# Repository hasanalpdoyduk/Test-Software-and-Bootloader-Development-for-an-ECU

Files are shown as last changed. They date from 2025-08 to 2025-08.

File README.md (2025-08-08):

# Test Software and Bootloader Development for an ECU

A bootloader has been developed that enables firmware updates without external programmers. The system runs on a 16-bit dsPIC33 microcontroller and supports CAN and UART interfaces.

Software is securely transferred via one of these interfaces and written to the microcontroller's memory using a block-based architecture that ensures data integrity during interrupts. To streamline the update process, a Python-based graphical user interface (GUI) was created for real-time control and monitoring.

Furthermore, a custom board containing the dsPIC33 MCU was designed and manufactured, successfully testing the bootloader and a PWM control implementation.
## Hardware Components

To initially load the bootloader onto the microcontroller or test the PWM control code, an external debugger is required. In this project, Microchip’s **PICkit 5** is used to program the dsPIC33 device.

| Type | Component |
| --- | --- |
| Microcontroller | [dsPIC33](https://ww1.microchip.com/downloads/aemDocuments/documents/OTH/ProductDocuments/DataSheets/dsPIC33EVXXXGM00X-10X-Family-Data-Sheet-DS70005144H.pdf) |
| CAN Transceiver | [MCP2561](https://ww1.microchip.com/downloads/en/DeviceDoc/20005167C.pdf) |
| LDO | [LF50](https://www.st.com/resource/en/datasheet/lfxx.pdf) |
| TVS Diode| [SMAJ36CA](https://www.vishay.com/docs/88390/smaj50a.pdf) |
| Schottky Diode| [SS8PH10HM3](https://www.vishay.com/docs/88989/ss8ph10.pdf) |

In addition to main components, other hardware parts such as resistors, capacitors, connectors, and oscillators are listed in the [Bill of Materials (BOM)](https://github.com/hasanalpdoyduk/Test-Software-and-Bootloader-Development-for-an-ECU/blob/main/KiCAD/ECU_SW_Control/Production_Files/BOM/ECU_SW_Control.csv).

## Block Diagram

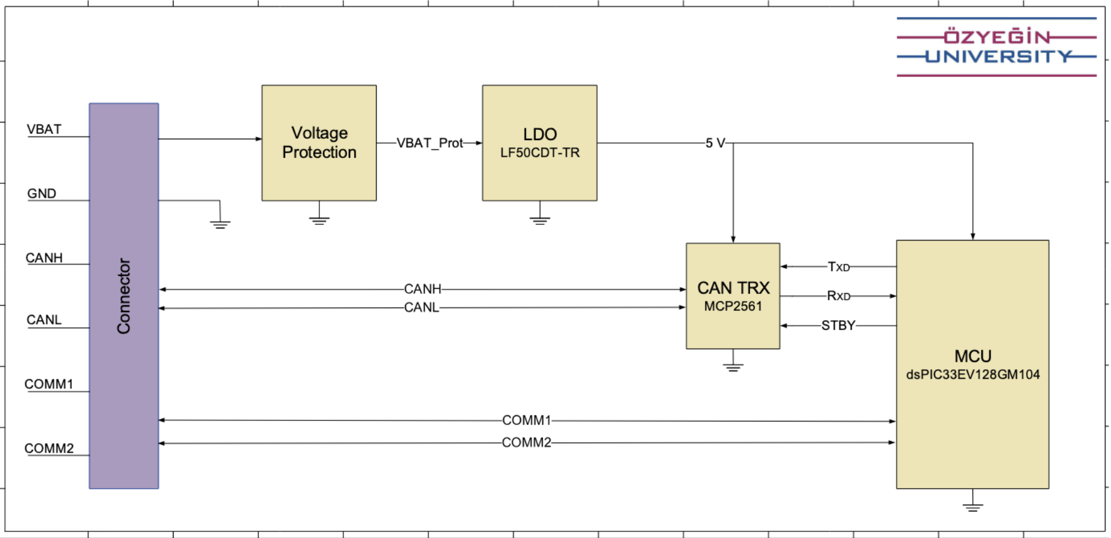
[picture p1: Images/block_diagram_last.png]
Block Diagram


The fully assembled PCB is shown here: [3D View of PCB](https://github.com/hasanalpdoyduk/Test-Software-and-Bootloader-Development-for-an-ECU/blob/main/Images/3D_view.pdf)

## Tools & Libraries

- KiCad: Used for schematic and PCB design.

- MATLAB Simulink Device Blocks for Microchip: Used to model and generate initial versions of embedded code.

- MPLAB X IDE: Used to compile and flash generated C code to the dsPIC33 MCU.

- Python (PyQt): Used for GUI development to support user interaction and test control.

## Supporting Sources

All technical details and explanations related to the project are available in the [project report](https://github.com/hasanalpdoyduk/Test-Software-and-Bootloader-Development-for-an-ECU/blob/main/Report_Presentation/EE402_Final_Report_AlpDoyduk_S025015_I%CC%87smail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). For more in-depth insights or specific inquiries, feel free to reach out via GitHub or refer to the resources listed below.

- [MCC dsPIC33 Bootlader - Video Guide](https://www.youtube.com/watch?v=2LhW11LbNhY): A step-by-step YouTube tutorial demonstrating how to implement a bootloader for dsPIC33 using Microchip Code Configurator (MCC).

- [Microchip Bootloader Library for 16-bit Devices](https://www.microchip.com/en-us/software-library/dspic33-pic24-bootloader): Official documentation and downloadable libraries for implementing bootloaders on 16-bit dsPIC33/PIC24 microcontrollers.

- [16-bit Bootloader Using MCC - Online Course](https://mu.microchip.com/16-bit-bootloaders-using-mcc-device-side): A Microchip University course explaining how to develop a bootloader for dsPIC33 using MCC, covering both theory and practice.
## Authors

- [Hasan Alp Doyduk](https://www.github.com/hasanalpdoyduk)
- [Ismail Akbaş](https://www.github.com/ismailakbas)

Supervised by: Asst. Prof. Umut Başaran

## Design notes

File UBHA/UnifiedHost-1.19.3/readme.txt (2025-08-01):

# README	General information
* Unified Bootloader Host Application 
- Used with the MCC Bootloader Generated Software Library for 8-bit or 16-bit MCU devices, or the 32-bit AN1388 bootloader.
- The graphical front-end of the 8-bit, 16-bit and 32-bit Bootloader project.

# Support
Email: MCC_Support@microchip.com
This application requires the Java 1.8 runtime.
For the required Java FX support, and an alternative source to the legacy Java installer can be found here:
Azul Zulu Community OpenJDK with OpenJFX is recommended; OpenJFX is required for use with UBHA.
https://www.azul.com/downloads/zulu-community/?&version=java-8-lts&package=jdk-fx 

Ensure to select the appropriate operating system, and architecture (32/64 bit).
Additional info: https://www.azul.com/products/zulu-enterprise/jdk-comparison-matrix/

Users of Microchip products can receive assistance through several channels:

 - Distributor or Representative
 - Local Sales Office
 - Field Application Engineer (FAE)
 - Technical Support

Customers should contact their distributor, representative or Field Application Engineer (FAE) for support.
Local sales offices are also available to help customers.
A listing of sales offices and locations may be found on the [Microchip web site][3].

Technical support is available through the [Microchip web site][4].

# CHANGELOG	A detailed changelog, intended for programmers
v 0.1.9:	Added readme, added logger, added checksum support to PIC32; added handling for record type 0x05 (currently ignored)
v 0.1.10:	Internal release
v 0.1.11:	Internal release
v 0.1.14:	Added PIC32 CRC bytes used at end of packets. Added Erase feature to USB PIC32 command chain. Extended Timeouts added support for 24-bit packet length.
v 0.1.15:	Fixed bug in PIC16 erase being half expected length during command chain. Added support for larger PIC18 device checksum commands, appending over previous Access Key bytes.
v 1.0.0:	Release version to support PIC24 family of devices. Added beta support for AVR devices.
v 1.15.0:   Release version to support dsPIC33 family of devices. Release support for AVR devices.
v 1.15.1:   Fixed bugs to support PIC-IOT WG Development Board, phantom byte for degenerate blocks and restrict data packet size to MAX_PACKET_SIZE - HEADER_SIZE.
v 1.16.0:   AVR code protocol modified to handle large future devices.
v 1.16.1:   Updated HID4JAVA library used for USB communication. Updates to AVR support to support MCC generated code. Extended PIC32 timeout(s) to 20s (from 8) UDP, USB
v 1.16.2:   32-bit devices no longer wait for responds from Reset Command. Bug fixes for 16-bit support: 1) Self Verify issue with larger parts with 2) no report, 3) End Address corruption on read properties, 4) Exception thrown on UART disconnect.
v 1.16.3:   Corrects an issue with 16-bit devices where flash data was unable to be written if located at the end of the last flash page.
v 1.17.0:   Add CAN and CAN-FD support for PIC24/dsPIC devices.  Expand console logging capability for PIC24/dsPIC devices.
v 1.17.1:   Improved console logging messages. Added provision to package the dependencies as a hotfix.
v 1.18.0:   Add I2C support for PIC24/dsPIC devices. Added support for select PIC18F Q device families (Q40, Q41, Q43, Q83, Q84).
v 1.19.0:   Add LIN support for PIC24/dsPIC devices. Fix issue causing readback errors when only a partial instruction worth of data is specified in the .hex file.
v 1.19.1:   Fix CAN DLL issue with latest USB drivers
v 1.19.2:   Fix MCP2221 DLL issue with latest drivers
v 1.19.3:   Robustness improvements to 16-bit UI implementation when UART driver loading fails.
            Fix issue of CAN BRS setting option being ignored.

# NEWS	A basic changelog, intended for users
-Incremented version information; see Changelog
-Added readme file on release of version: 0.1.14
-Added Checksum support for PIC32
-Bug fixes, Added Release Notes v 0.1.15 along with readme file. Added support for up to 32-bit checksum value calculation.
-Added Synch Byte expectation to AVR packet support.
-Fixed Typo in Help-->About text which indicated incorrect Utility version
-Added logger support requires launching from command prompt with below text:
* -Djava.util.logging.config.file="C:\<DirectoryLocation>"
- Bugfix for 16-bit flash write.

# Known Issues
- When using a version of java greater than v1.8.0_251, selecting a UART COM port and selecting "Apply" causes the Unified Bootloader Host Application to crash. In order to avoid this please ensure to use
a version of java at or below version 1.8.0_251. 
- The warning 'Application Offset exist between ROWS/PAGE boundaries' might be shown incorrectly, even though the application offset is at the start of a page. Please make sure that the application start adress is at the beginning of a page by referring to the device datasheet.

# Debug Log
The UBHA supports the ability to view Debug Logger message through use of the packaged logging.properties file.
i.e.: To Launch from Command Prompt
>java -Djava.util.logging.config.file="<Drive: e.g. C>:\<MyDirectory>\<UnifiedHost-version>\logging.properties" -jar UnifiedHost-<version>.jar

# INSTALL	Installation instructions
Installation of Java JRE

# COPYING / LICENSE	Copyright and licensing information
See LICENSE.txt for licensing information.

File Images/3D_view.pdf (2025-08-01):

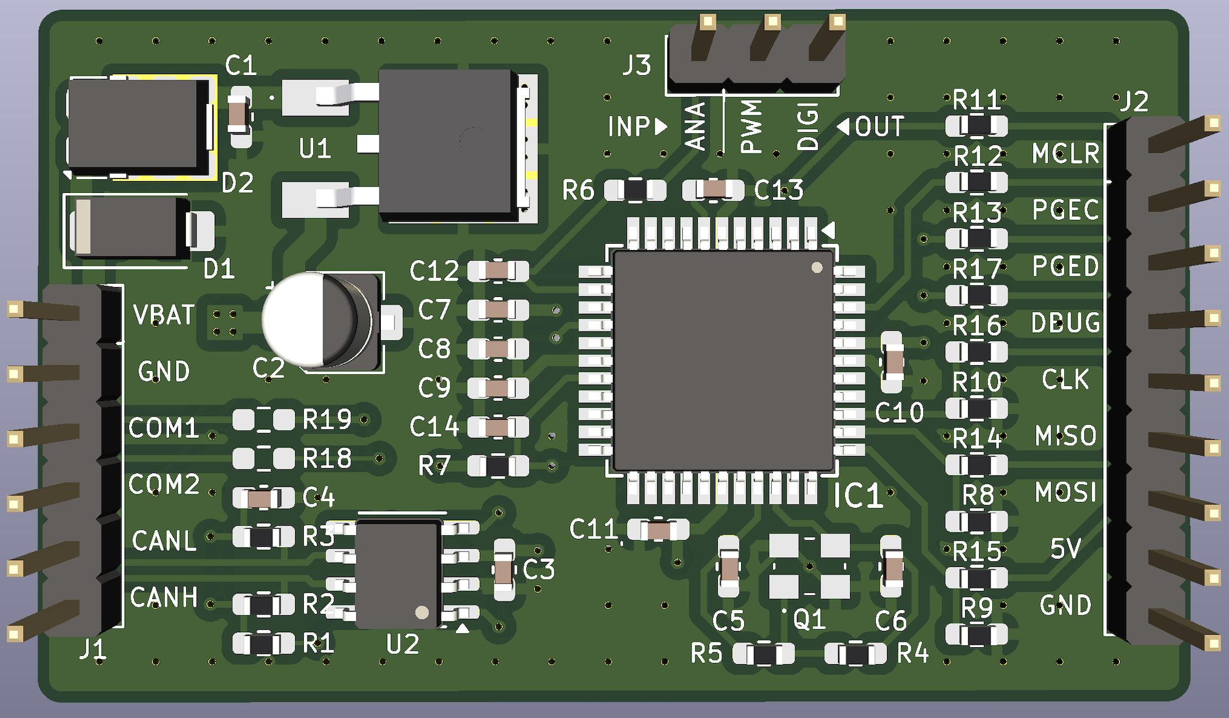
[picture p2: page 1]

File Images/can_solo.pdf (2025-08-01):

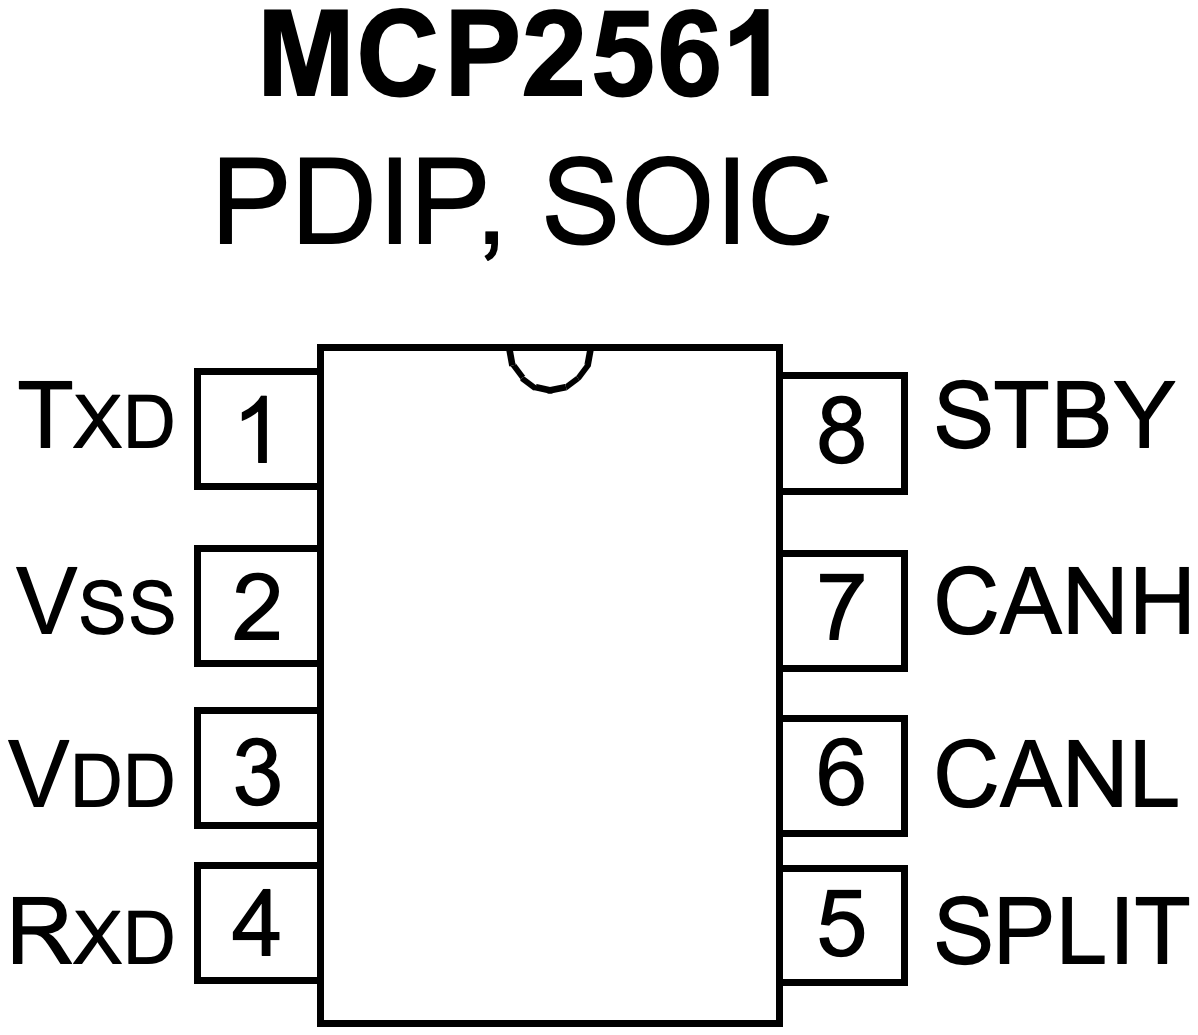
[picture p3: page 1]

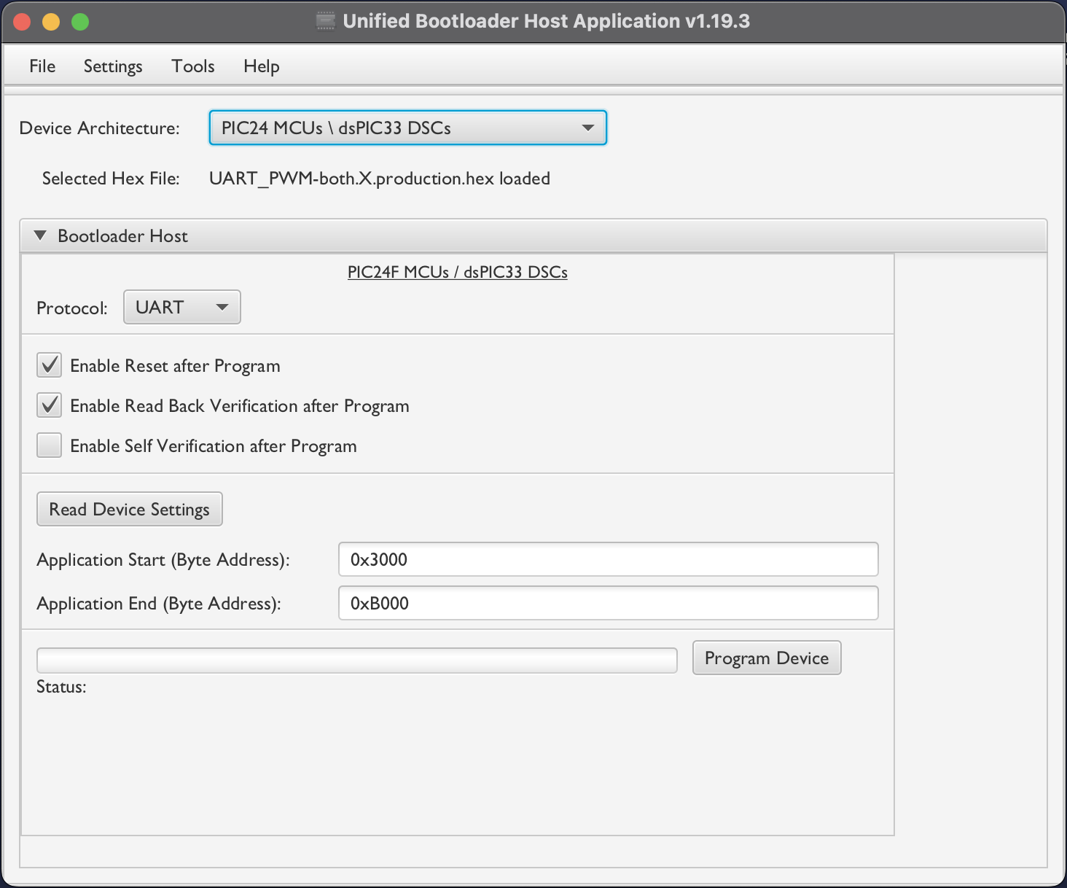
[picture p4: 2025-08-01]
Images/UBHA_select_HEX.png

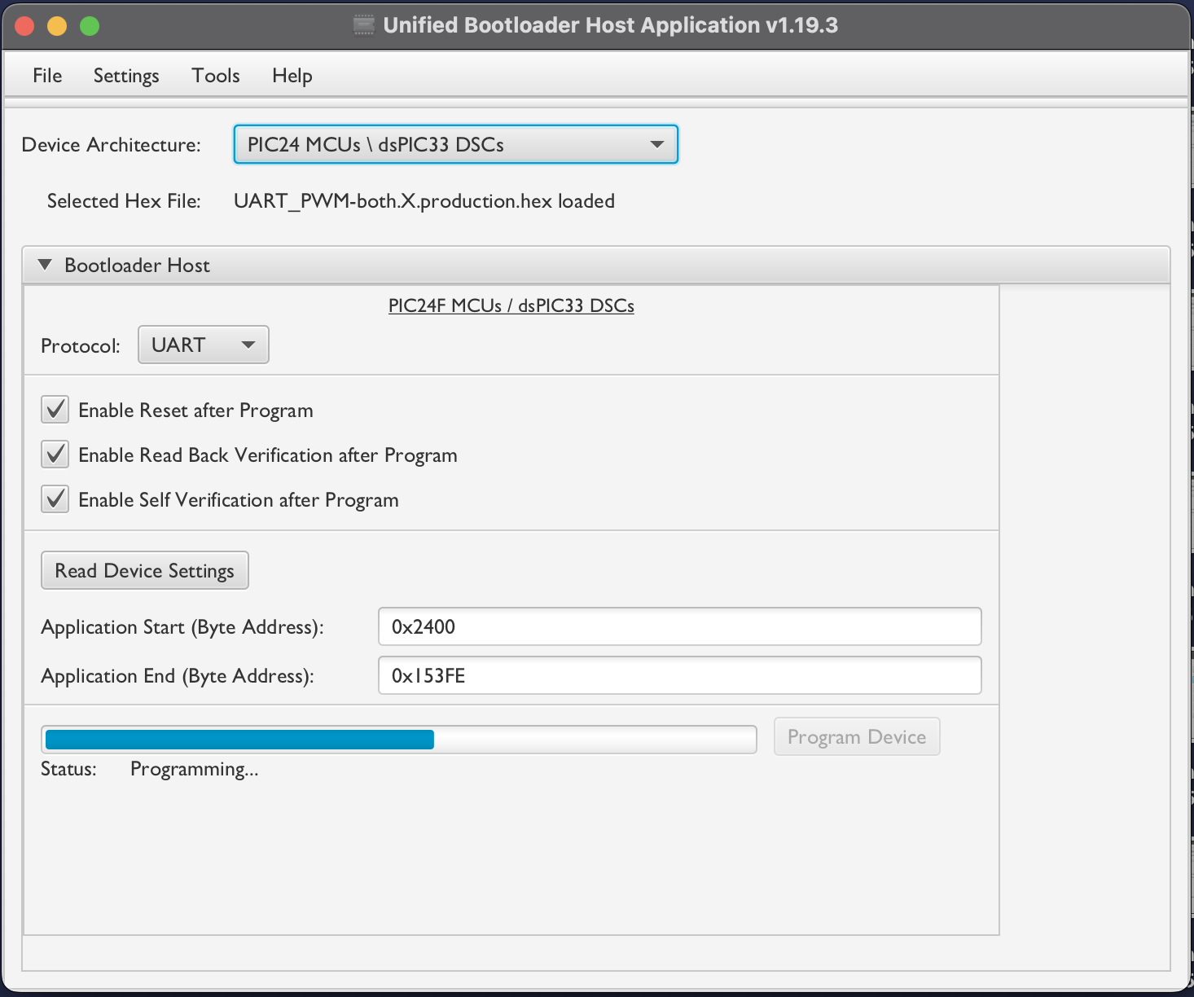
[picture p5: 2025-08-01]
Images/UBHA_programming.png

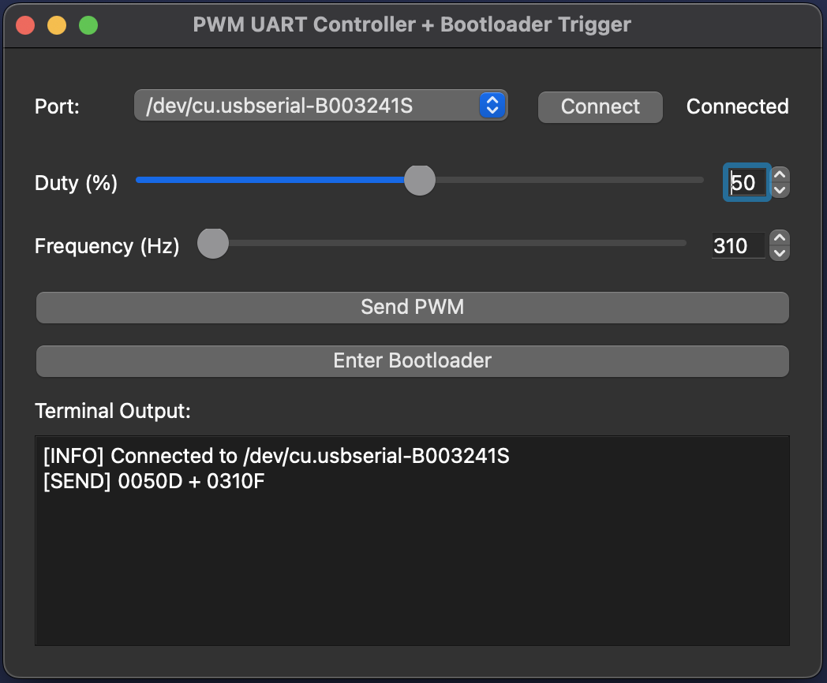
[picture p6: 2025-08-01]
Images/UART_GUI1.png

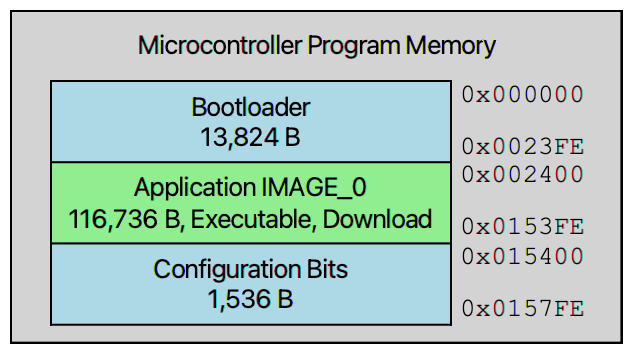
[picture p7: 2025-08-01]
Images/bootloader_register_map.png

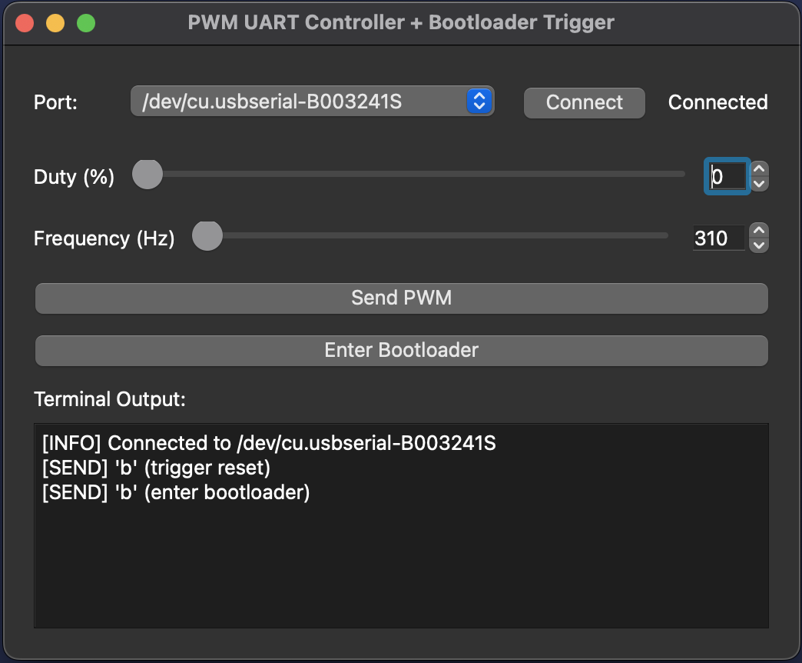
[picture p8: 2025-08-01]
Images/Boot_GUI_enter_b.png

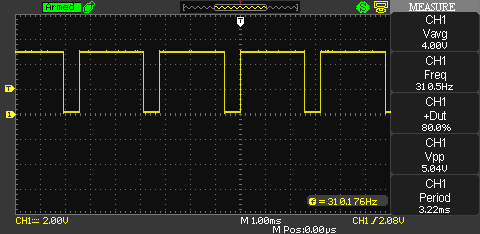
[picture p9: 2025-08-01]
Images/OscillatorSs/ADS00002.BMP

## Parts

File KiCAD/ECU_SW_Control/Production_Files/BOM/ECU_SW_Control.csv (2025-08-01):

Reference | Value | Footprint | Qty | DNP | Ordering_Code | Ordering_Link
C1,C3 | 0.1uF/50V | Capacitor_SMD:C_0603_1608Metric_Pad1.08x0.95mm_HandSolder | 2 |  | CGA3E2X7R1H104K080AA | -- mixed values --
C2 | 2.2uF/50V | Capacitor_SMD:CP_Elec_4x5.3 | 1 |  | SC1H225M04005VR | https://ozdisan.com/pasif-komponentler/kapasitorler/aluminyum-kapasitorler/SC1H225M04005VR/27464
C4 | 4700pF/50V | Capacitor_SMD:C_0603_1608Metric_Pad1.08x0.95mm_HandSolder | 1 |  | CL10B472KB8WPNC | https://www.digikey.com/en/products/detail/samsung-electro-mechanics/CL10B472KB8WPNC/5961016
C5,C6 | 8.2pF/50V | Capacitor_SMD:C_0603_1608Metric_Pad1.08x0.95mm_HandSolder | 2 |  | CL10C8R2CB81PNC | https://www.digikey.com/en/products/detail/samsung-electro-mechanics/CL10C8R2CB81PNC/5961050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
C7 | 2.2uF/25V | Capacitor_SMD:C_0603_1608Metric_Pad1.08x0.95mm_HandSolder | 1 |  | GRT188C71E225KE13D | https://www.digikey.com/en/products/detail/murata-electronics/GRT188C71E225KE13D/16033473
C8,C9,C11 | 100nF/50V | Capacitor_SMD:C_0603_1608Metric_Pad1.08x0.95mm_HandSolder | 3 |  | CL10B104KB8WPNC | https://www.digikey.com/en/products/detail/samsung-electro-mechanics/CL10B104KB8WPNC/5961338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
C10 | 100nF/25V | Capacitor_SMD:C_0603_1608Metric_Pad1.08x0.95mm_HandSolder | 1 |  | CGA3E2X7R1E104K080AA | https://www.digikey.com/en/products/detail/tdk-corporation/CGA3E2X7R1E104K080AA/2443145
C12,C14 | 10nF/50V | Capacitor_SMD:C_0603_1608Metric_Pad1.08x0.95mm_HandSolder | 2 |  | GCM188R71H103KA37D | https://www.digikey.com/en/products/detail/murata-electronics/GCM188R71H103KA37D/1641652
C13 | 10uF/16V | Capacitor_SMD:C_0603_1608Metric_Pad1.08x0.95mm_HandSolder | 1 |  | GRT188R61C106ME13D | https://www.digikey.com/en/products/detail/murata-electronics/GRT188R61C106ME13D/5416740
D1 | SMAJ36CA | Diode_SMD:D_SMA | 1 |  | SMAJ36CA-AT/TR7 | https://ozdisan.com/guc-yari-iletkenleri/diyotlar-modul-diyotlar-ve-dogrultucular/tvs-diyotlar/SMAJ36CA-ATTR7/973895
D2 | V10P10HM3_A_H | Package_TO_SOT_SMD:TO-277A | 1 |  | V10P10HM3_A/H | https://www.digikey.com/en/products/detail/vishay-general-semiconductor-diodes-division/V10P10HM3-A-H/5427050
IC1 | dsPIC33EV128GM104 | Package_QFP:TQFP-44_10x10mm_P0.8mm | 1 |  | dsPIC33EV128GM104 | https://www.microchip.com/en-us/product/dspic33ev128gm104
J1 | Conn_01x06 | Connector_PinHeader_2.54mm:PinHeader_1x06_P2.54mm_Vertical | 1 |  | 5PS1SDA85-106G0NNNAL-00 | https://ozdisan.com/Product/Detail/354014/5PS1SDA85-106G0NNNAL-00
J2 | Conn_01x09 | Connector_PinHeader_2.54mm:PinHeader_1x09_P2.54mm_Vertical | 1 |  | DS1023-1X9S21 | https://ozdisan.com/Product/Detail/421997/DS1023-1X9S21
J3 | Conn_01x03 | Connector_PinHeader_2.54mm:PinHeader_1x03_P2.54mm_Vertical | 1 |  | DS1023-1X3SF11 | https://ozdisan.com/Product/Detail/454405/DS1023-1X3SF11
Q1 | CX3225CA-12MHz | ECU_SW_Control_lib:CX3225SB40000D0FLJCC | 1 |  | CX3225CA12000D0HSSCC | https://www.digikey.com/en/products/detail/kyocera-avx/CX3225CA12000D0HSSCC/4453836
R1 | 300R/1% | Resistor_SMD:R_0603_1608Metric_Pad0.98x0.95mm_HandSolder | 1 |  | ERJ-3EKF3000V | https://ozdisan.com/passive-components/resistors/smt-smd-and-chip-resistors/ERJ-3EKF3000V/614721
R2,R3 | 60.4R/1% | Resistor_SMD:R_0603_1608Metric_Pad0.98x0.95mm_HandSolder | 2 |  | ERJ-U03F60R4V | https://www.digikey.com/en/products/detail/panasonic-electronic-components/ERJ-U03F60R4V/11634997
R4 | 1M/1% | Resistor_SMD:R_0603_1608Metric_Pad0.98x0.95mm_HandSolder | 1 |  | ERJ-3EKF1004V | https://www.digikey.com/en/products/detail/panasonic-electronic-components/ERJ-3EKF1004V/196033
R5,R6,R11,R12,R13,R14,R15,R16,R17 | 100R/1% | Resistor_SMD:R_0603_1608Metric_Pad0.98x0.95mm_HandSolder | 9 |  | ERJ-3EKF1000V | https://www.digikey.com/en/products/detail/panasonic-electronic-components/ERJ-3EKF1000V/196074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
R7,R8,R9,R10 | 10k/1% | Resistor_SMD:R_0603_1608Metric_Pad0.98x0.95mm_HandSolder | 4 |  | ERJ-3EKF1002V | https://www.digikey.com/en/products/detail/panasonic-electronic-components/ERJ-3EKF1002V/196066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
R18,R19 | 0/5% | Resistor_SMD:R_0603_1608Metric_Pad0.98x0.95mm_HandSolder | 2 | DNP | 0603SAJ0000TDE | https://ozdisan.com/pasif-komponentler/direncler/smt-smd-ve-cip-direncler/0603SAJ0000TDE/602709
U1 | LF50_TO252 | ECU_SW_Control_lib:LF50CDTTRY | 1 |  | LF50CDT-TRY | https://www.digikey.com/en/products/detail/stmicroelectronics/LF50CDT-TRY/2193170
U2 | MCP2561-E-SN | Package_SO:SOIC-8_3.9x4.9mm_P1.27mm | 1 |  | MCP2561-E-SN | https://ozdisan.com/entegre-devreler-icler/interface-entegreleri/driver-receiver-ve-transceiver-entegreleri/MCP2561-ESN/457815

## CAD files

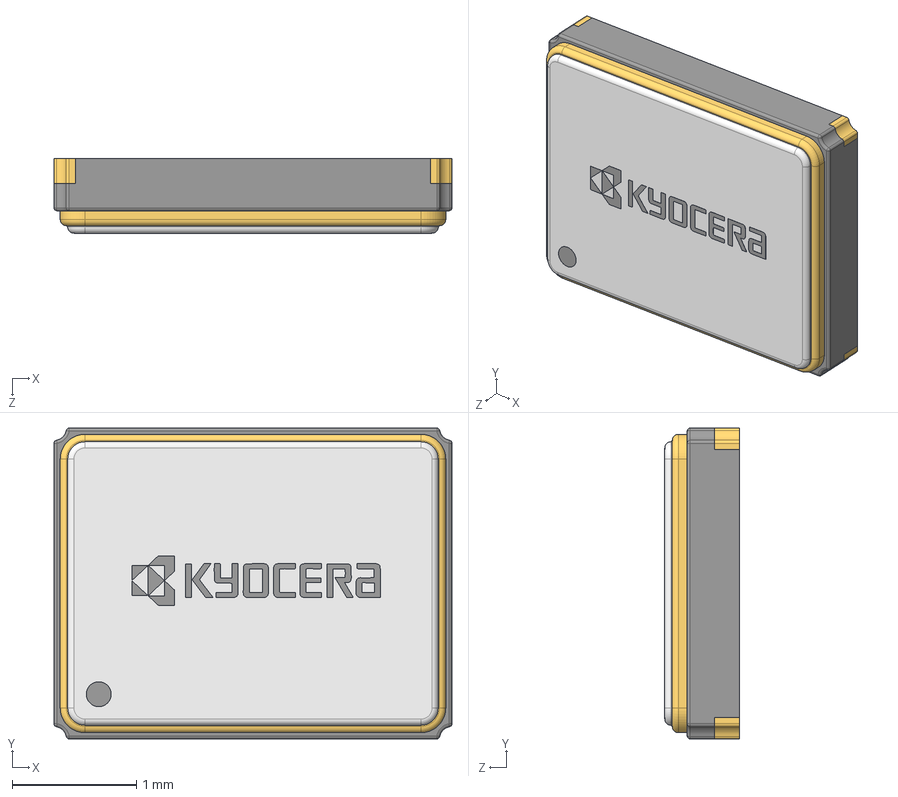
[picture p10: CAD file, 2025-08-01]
KiCAD/ECU_SW_Control/External_lib/LIB_CX3225CA12000D0KPSC1/CX3225CA12000D0KPSC1/3D/CX3225CA12000D0KPSC1.stp
3.20 x 2.50 x 0.601 mm
CX3225SB25000D0FFFCC_Pin 1 Chamfer
Kyocera Logo

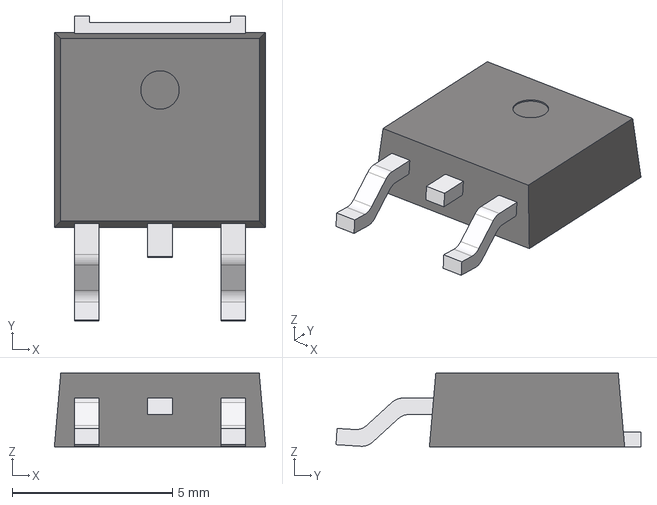
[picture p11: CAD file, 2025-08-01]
KiCAD/ECU_SW_Control/External_lib/LIB_LF50/3D/LF50CDT-TR.stp
6.60 x 9.53 x 2.30 mm

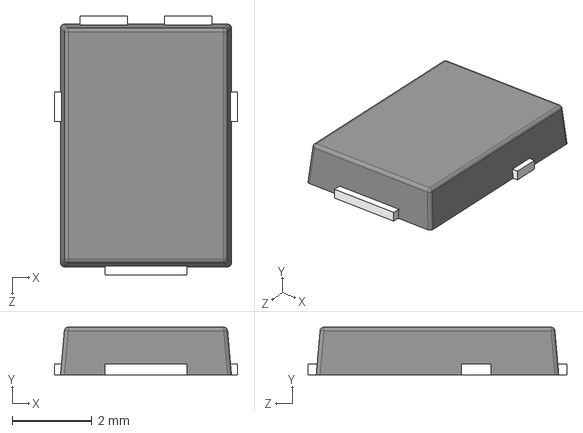
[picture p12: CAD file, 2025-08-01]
KiCAD/ECU_SW_Control/External_lib/LIB_V10P10HM3_A_H/V10P10HM3_A_H/3D/V10P10HM3_A_H.stp
4.60 x 1.20 x 6.50 mm

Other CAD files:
KiCAD/ECU_SW_Control/External_lib/LIB_CX3225CA12000D0KPSC1/CX3225CA12000D0KPSC1/Allegro/cx3225sb40000d0fljcc.psm
KiCAD/ECU_SW_Control/External_lib/LIB_CX3225CA12000D0KPSC1/CX3225CA12000D0KPSC1/DEHDL/cx3225ca12000d0kpsc1/chips/chips.prt
KiCAD/ECU_SW_Control/External_lib/LIB_V10P10HM3_A_H/V10P10HM3_A_H/Allegro/v10p10hm3_ah.psm
KiCAD/ECU_SW_Control/External_lib/LIB_V10P10HM3_A_H/V10P10HM3_A_H/DEHDL/v10p10hm3_a_h/chips/chips.prt

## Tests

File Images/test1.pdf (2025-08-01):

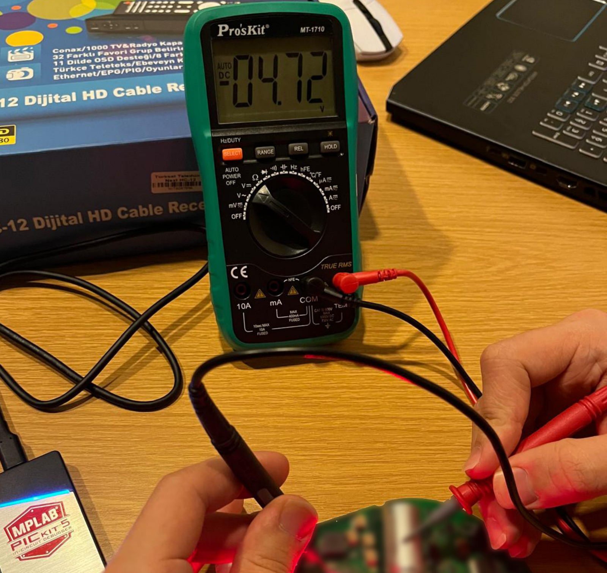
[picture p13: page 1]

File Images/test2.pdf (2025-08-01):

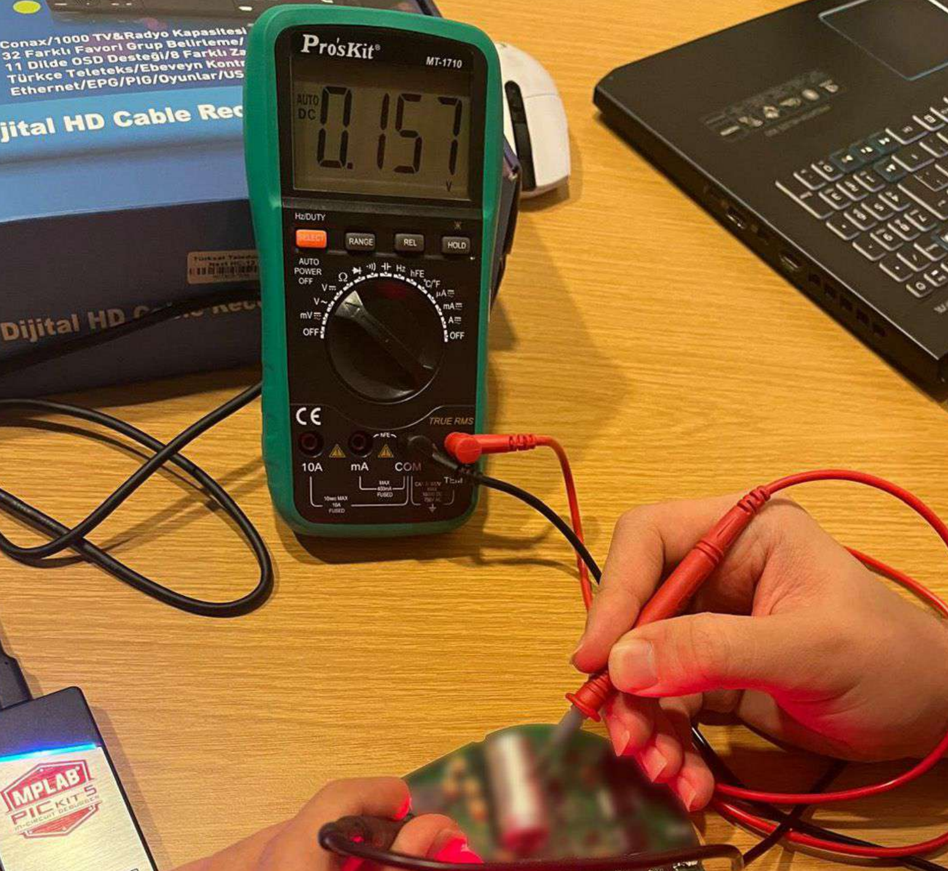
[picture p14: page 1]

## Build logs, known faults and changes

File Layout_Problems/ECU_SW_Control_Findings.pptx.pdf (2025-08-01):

# ECU SW CONTROL PROJECT DESIGN FINDINGS

# LF50CDT-TRY LDO

## - An LDO with 12V input voltage and 5V output voltage was used. Issues such as power dissipation and thermal analysis should be evaluated by considering parameters such

as ambient temperature and output current. I suggest you research this topic.

# Finding 1: Thermal Issue

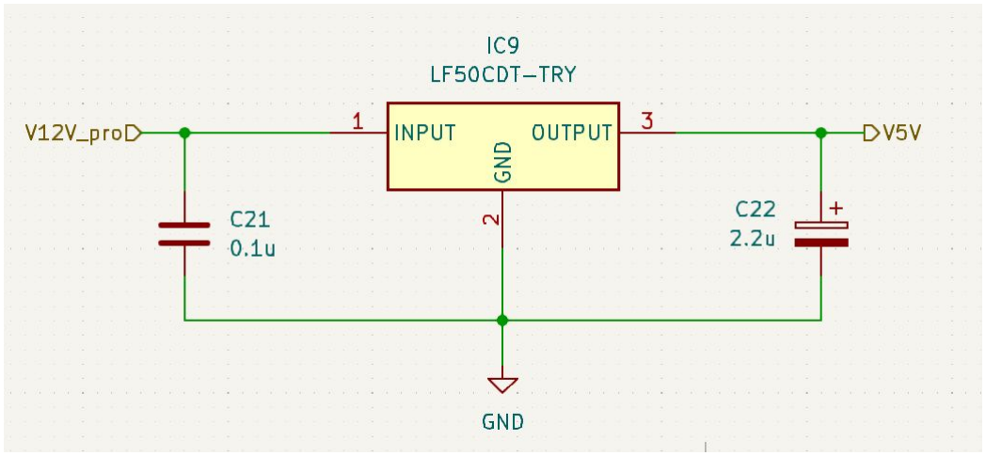
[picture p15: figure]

- Capacitors can be placed closer to the LDO input and output pins.

# Finding 2: Capacitor Placement

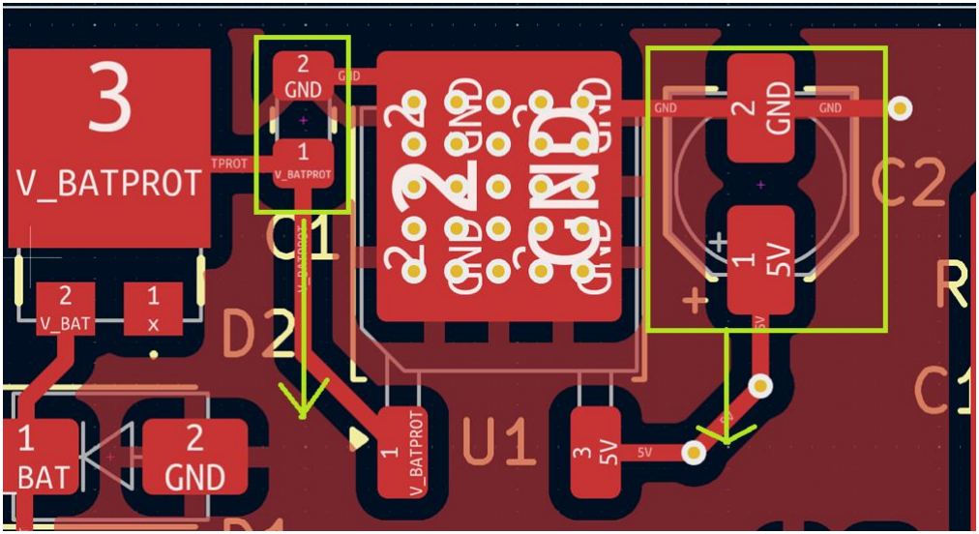
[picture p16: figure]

## - 5V can enter the Electrolytic capacitor after the LDO output pin and then be

distributed to the board from the 3rd layer with vias.
Via numbers are related to current capability. I suggest you to investigate.

# Finding 3: 5V Voltage

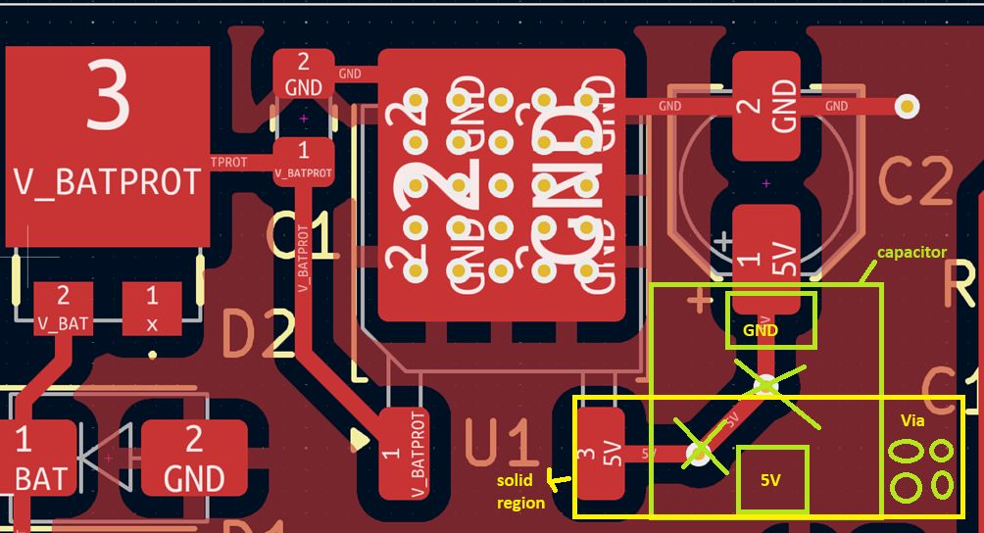
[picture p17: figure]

## - Battery voltage tracks can be thickened if necessary, according to the current

requirement of the system.
You can download and check the PCB Saturn Tool for current calculation.

# Finding 4: Current Capability

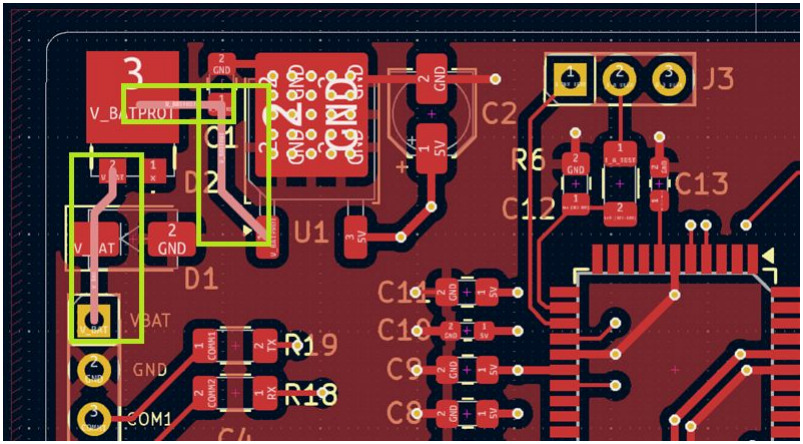
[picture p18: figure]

# CAN INTERFACE

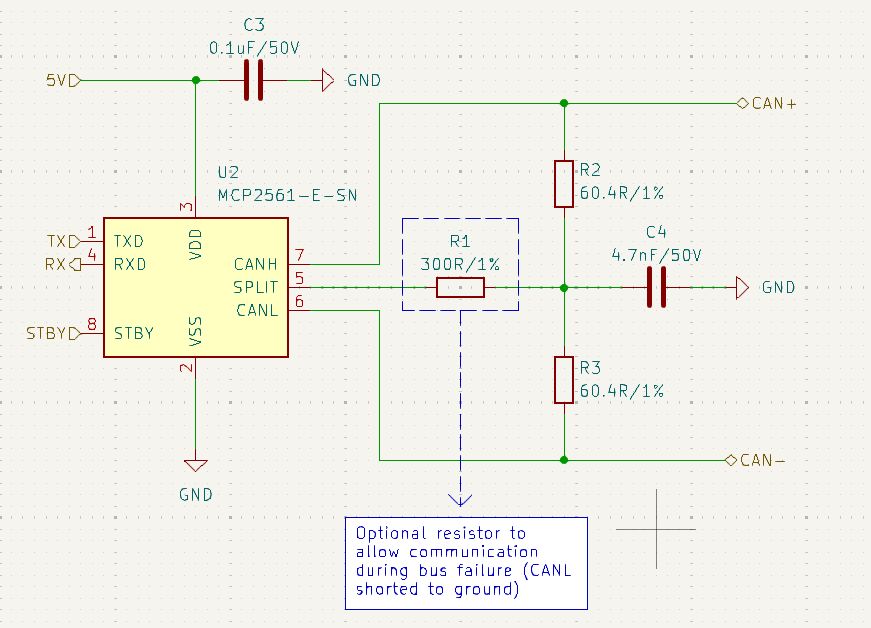
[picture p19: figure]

### https://www.onsemi.com/pub/Collater al/AND8169-D.PDF (https://www.onsemi.com/pub/Collateral/AND8169-D.PDF)

### https://www.onsemi.com/pub/Collater al/AND8253-D.PDF (https://www.onsemi.com/pub/Collateral/AND8253-D.PDF)

- The following documents about the use of TVS (Transient-voltage-suppression diode, CMC (Common Mode Choke) for CAN Communication interfaces should be examined. You can also get information about the layout placement of these components.

# Finding 5: Use of TVS and CMC

# dsPIC33EV128

# Finding 6: Oscillator

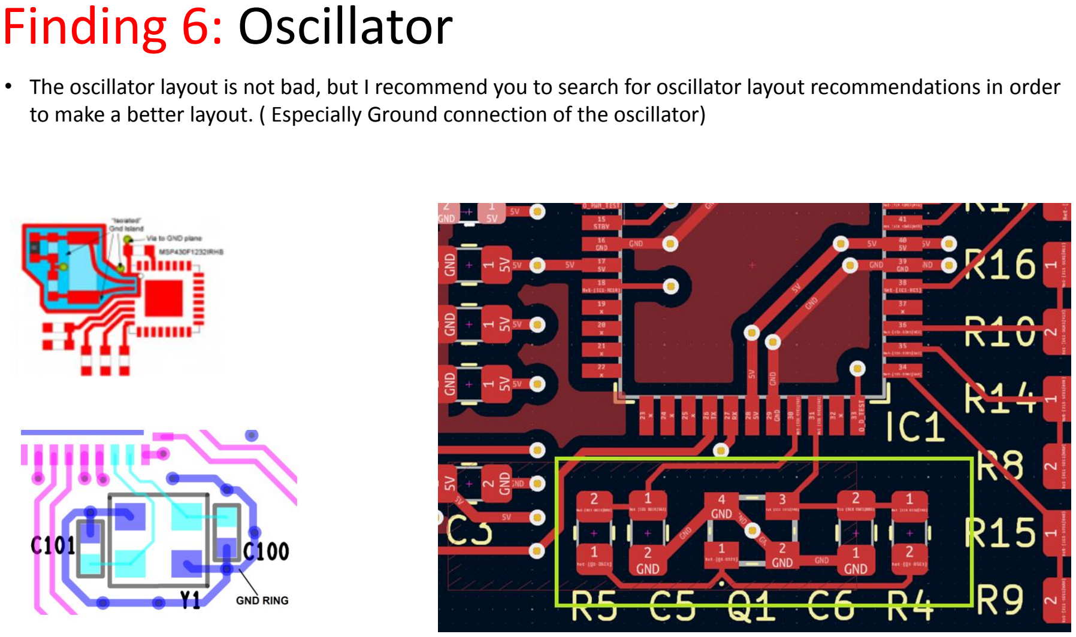
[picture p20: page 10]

- The oscillator layout is not bad, but I recommend you to search for oscillator layout recommendations in order to make a better layout. ( Especially Ground connection of the oscillator)

- 5V voltage should pass through the capacitors respectively and input to pin 17.

# Finding 7: 5V Voltage Flow Direction

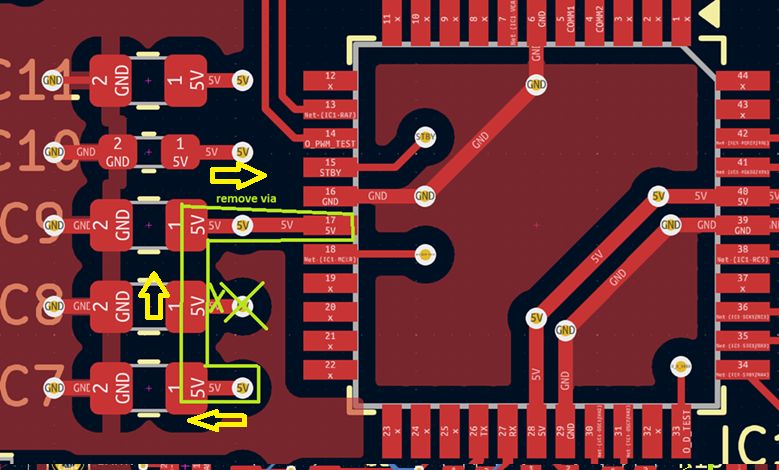
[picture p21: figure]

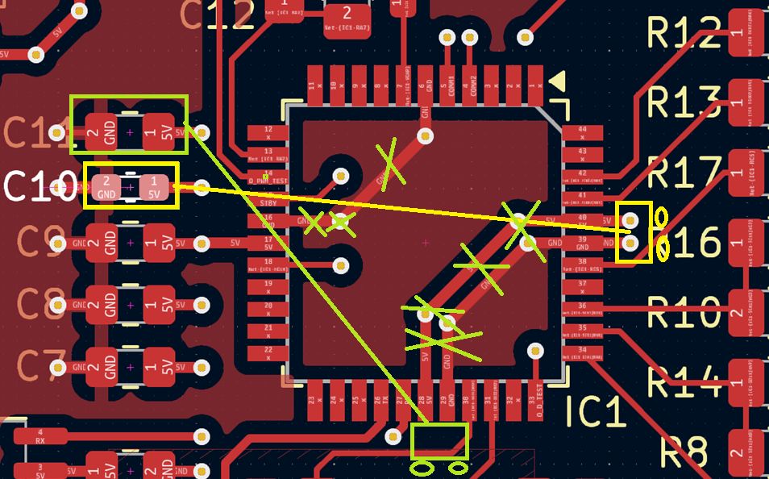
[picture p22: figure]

- Capacitors C10-C11 must be placed close to the corresponding pins.
- No need for intermediate connections and vias. After moving the capacitors to the right places, you will be able to get the 5V and GND signals from the 2nd and 3rd layer with the vias.

# Finding 8: Capacitor Placement

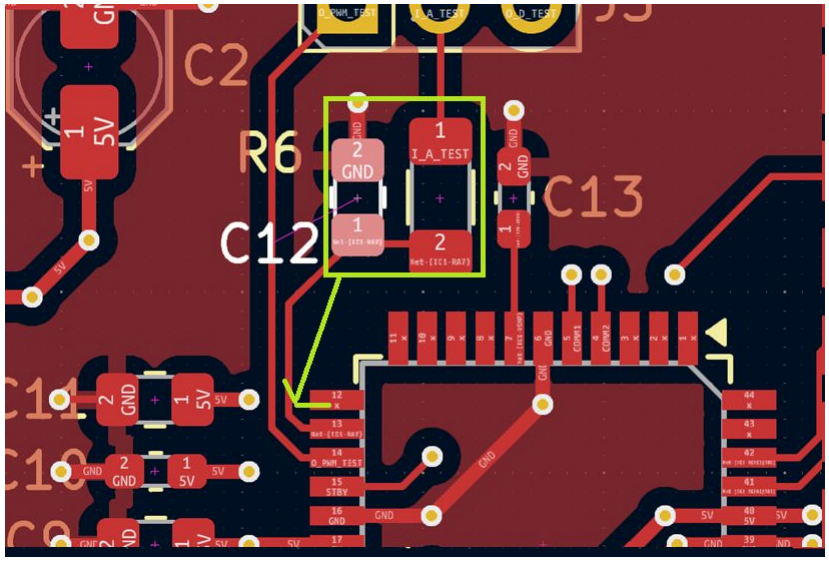
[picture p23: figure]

- R6-C12 low pass filter components should be placed as close as possible to the relevant pin. (Tip: Since C10 and C11 capacitors will be moved up, these components can be shifted to the free space).

# Finding 9: Low Pass Filter Placement

# Layout Issues

# Finding 10: EMC and EMI Improvement

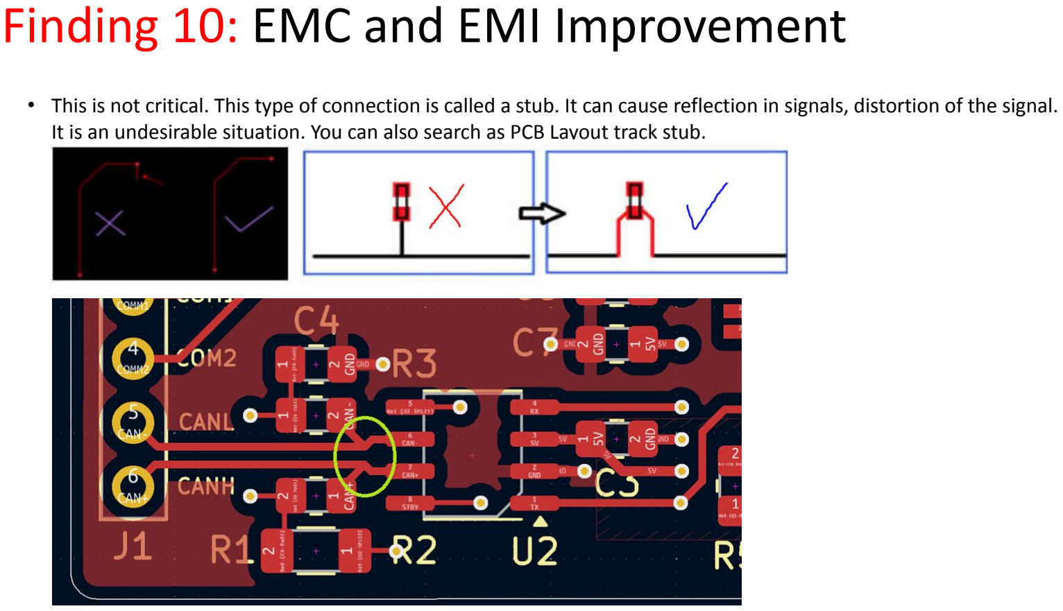
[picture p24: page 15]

- This is not critical. This type of connection is called a stub. It can cause reflection in signals, distortion of the signal. It is an undesirable situation. You can also search as PCB Layout track stub.

- Improvements in EMC and EMI can be achieved by improving ground connections and obtaining low impedance connections by adding GROUND polygon to the bottom layer. Thus, noise and interference can be reduced.

# Finding 11: EMC and EMI Improvement

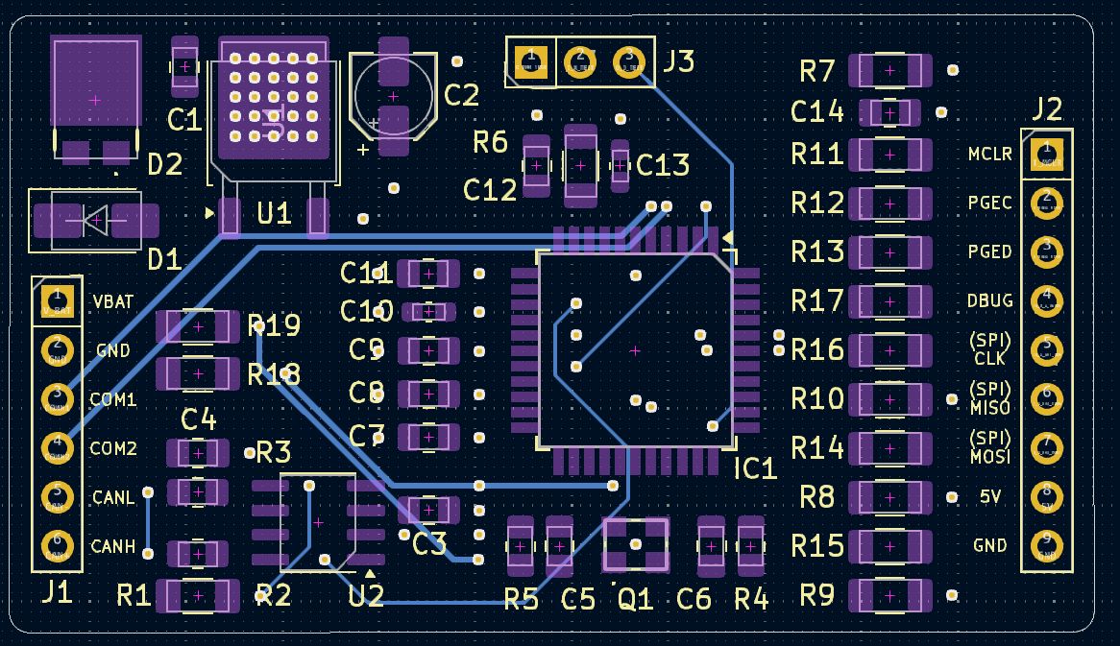
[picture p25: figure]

- The number of ground via seems to be a bit low. The GROUND vias can be placed as green marked and GROUND copper can be filled. Stitching ground vias is essential for high quality ground connections, lower noise, more stable performance and a more reliable design.

# Finding 12: EMC and EMI Improvement

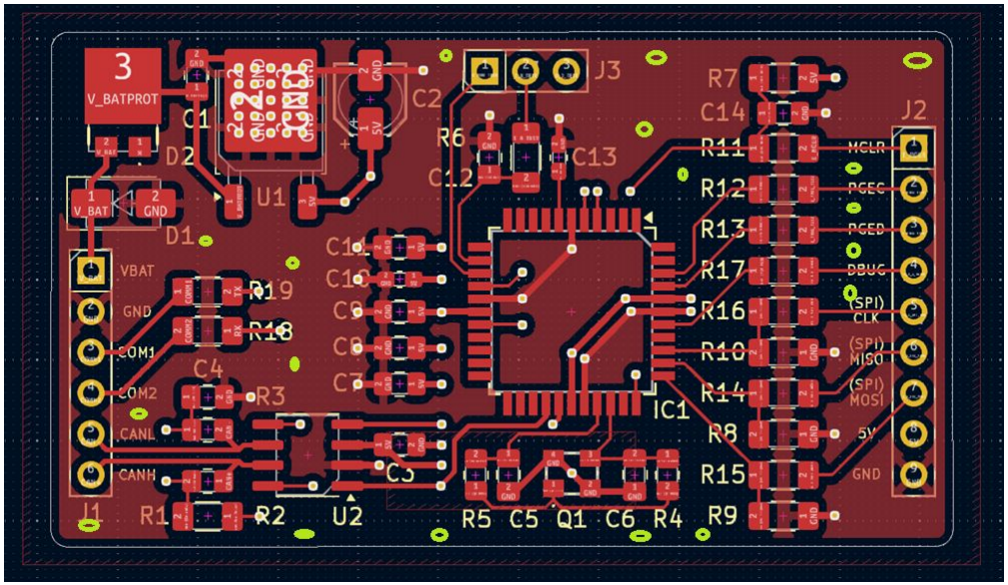
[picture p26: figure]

- For the references of the signals in the bottom layer, the free space in layer 3 can be filled with the GROUND polygon.
- In this way, the signals in the bottom layer get their ground references from the ground plane in layer 3 instead of the ground plane in layer 2 which is far away. This improves signal integrity.

# Finding 13: EMC and EMI Improvement

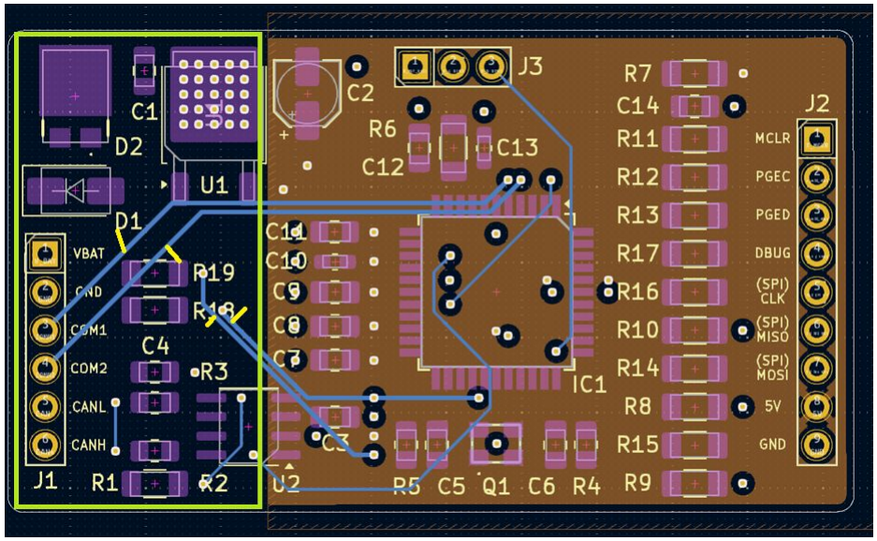
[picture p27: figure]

- Not too critical, just a tip for future projects, if you place the TX-RX vias as shown in the image, you can place the decoupling capacitor closer and neater to the 5V and GND pins. This will give you a smoother voltage signal.

# Finding 14: Capacitor Placement

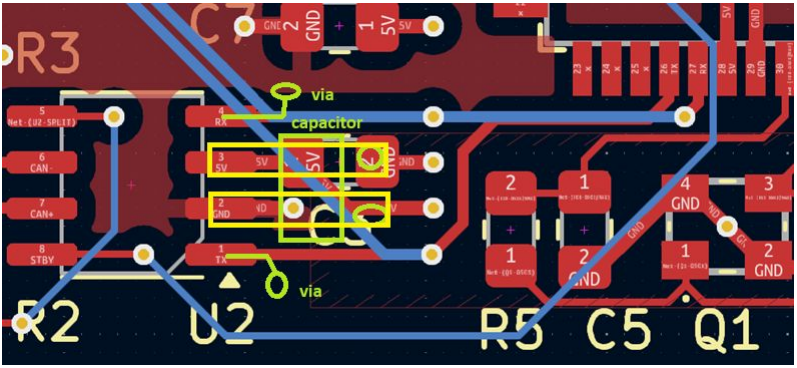
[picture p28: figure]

- This is not critical, but it can give you a hint for future projects. You can improve your design with small improvements. For example, if you can move the components on the right up a little bit, the GROUND polygon can be formed from the space you have created below and fill the empty spaces on the left ( yellow marked). This is just an example, you can examine the whole board and make such improvements.
- Remember, improvements are always possible to improve your design. You can achieve a better design with small touches.

# Finding 15: EMC and EMI Improvement

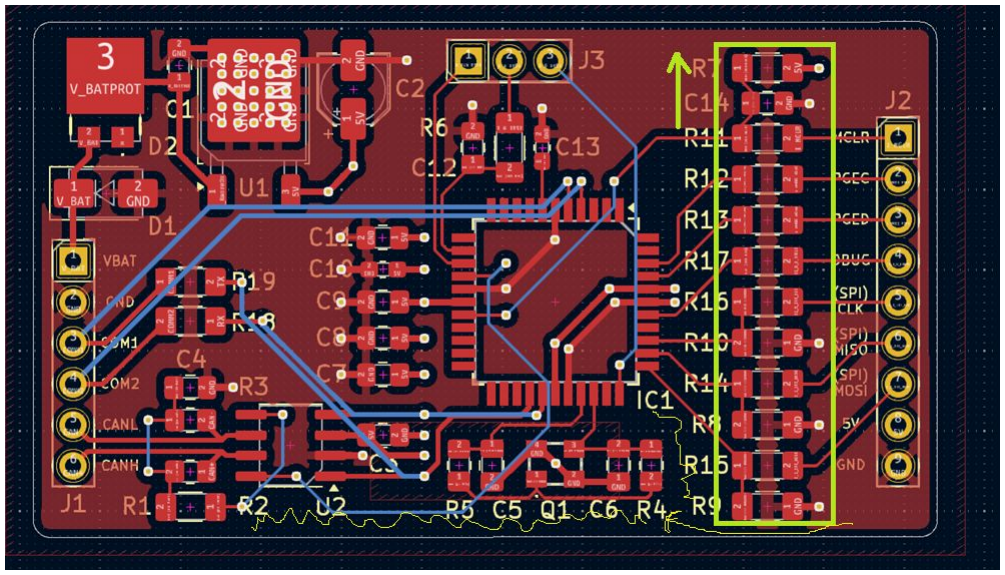
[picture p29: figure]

# Finding 16: Layout Tips

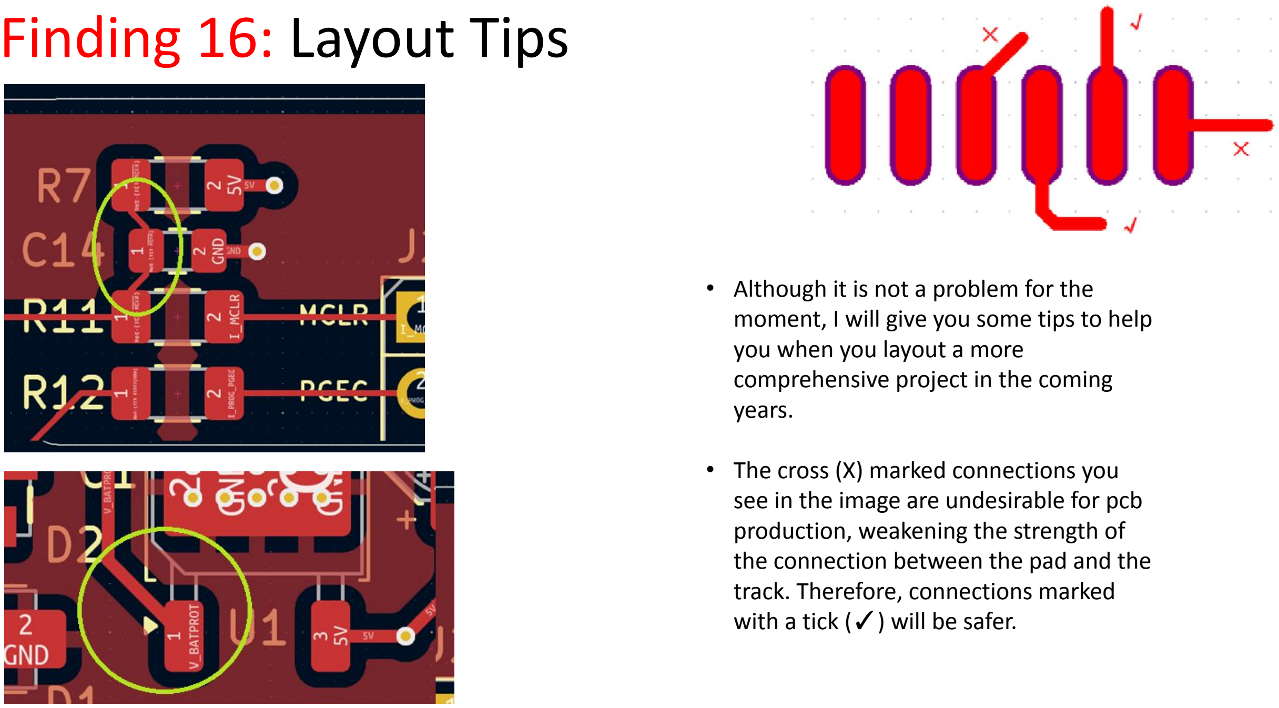
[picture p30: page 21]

- Although it is not a problem for the moment, I will give you some tips to help you when you layout a more comprehensive project in the coming years.
- The cross (X) marked connections you see in the image are undesirable for pcb production, weakening the strength of the connection between the pad and the track. Therefore, connections marked with a tick (✓) will be safer.

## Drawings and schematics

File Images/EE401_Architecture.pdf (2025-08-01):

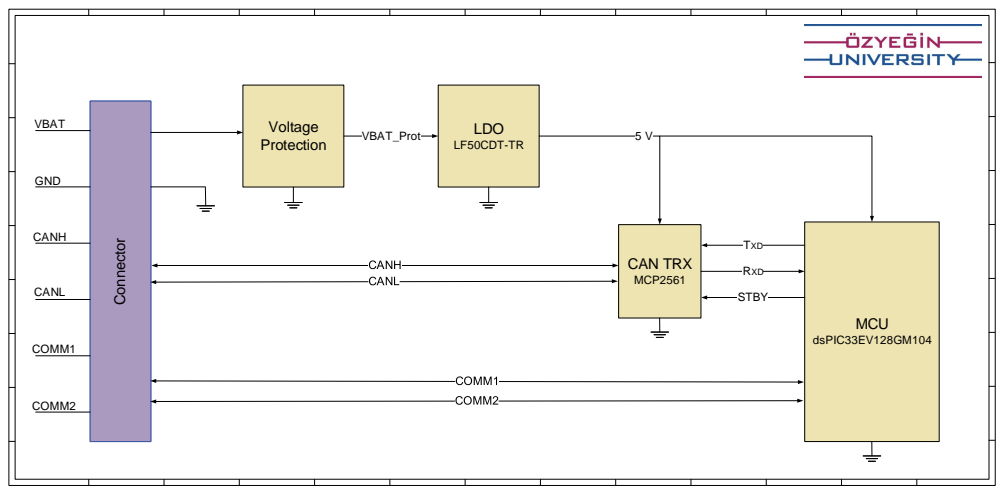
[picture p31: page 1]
LDO; LF50CDT; Connector; CAN TRX; MCP2561; MCU; dsPIC33EV128GM104; VBAT; GND; CANL; COMM1; CANH; COMM2; Voltage; Protection; VBAT_Prot; TXD RXD; STBY

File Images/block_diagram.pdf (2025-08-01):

### LDO

### Voltage

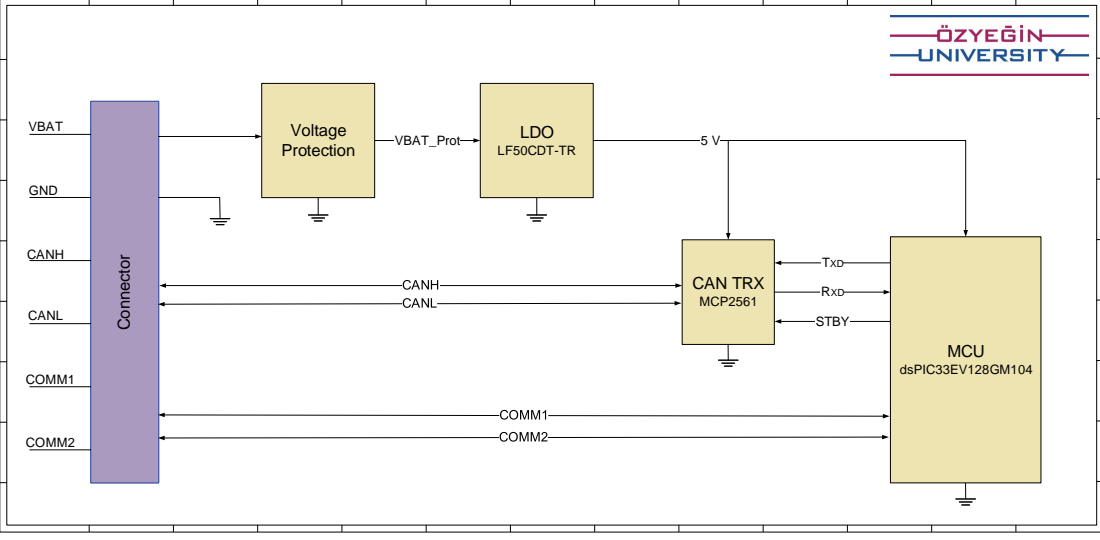
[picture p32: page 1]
LF50CDT-TR; Connector; CAN TRX; MCP2561; MCU; dsPIC33EV128GM104; VBAT; GND; CANL; COMM1; CANH; COMM2; Protection; VBAT_Prot; TXD; RXD; STBY

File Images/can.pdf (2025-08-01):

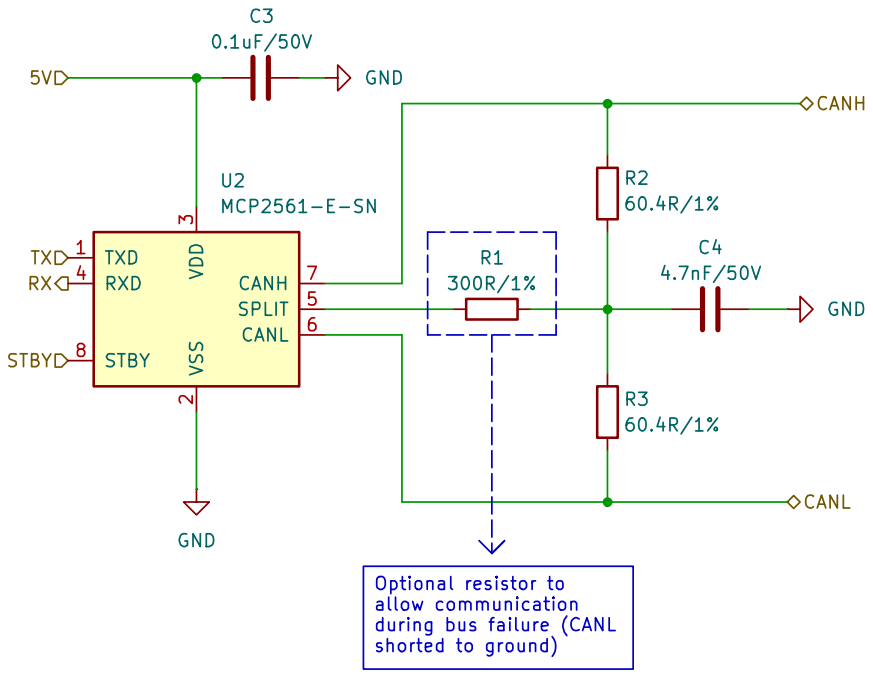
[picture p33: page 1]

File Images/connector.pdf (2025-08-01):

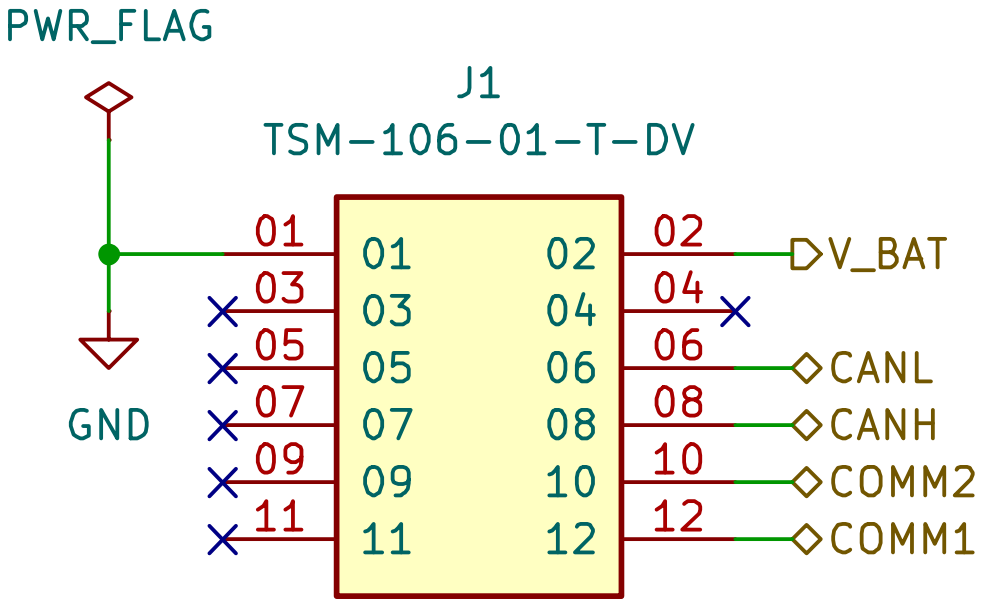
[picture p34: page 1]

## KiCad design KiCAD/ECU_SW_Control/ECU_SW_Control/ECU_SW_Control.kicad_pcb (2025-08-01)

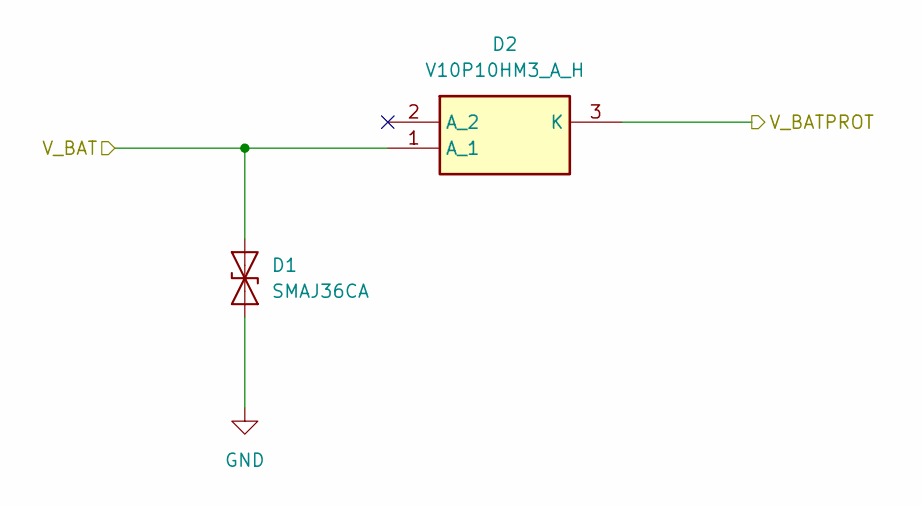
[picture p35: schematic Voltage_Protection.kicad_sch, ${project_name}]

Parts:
D1: SMAJ36CA; D_SMA
D2: V10P10HM3_A_H; TO-277A

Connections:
/Connector/V_BAT: D1.1 (A1), D2.1 (A_1); also elsewhere on the board
/LDO/V_BATPROT: D2.3 (K); also elsewhere on the board
GND: D1.2 (A2); also elsewhere on the board

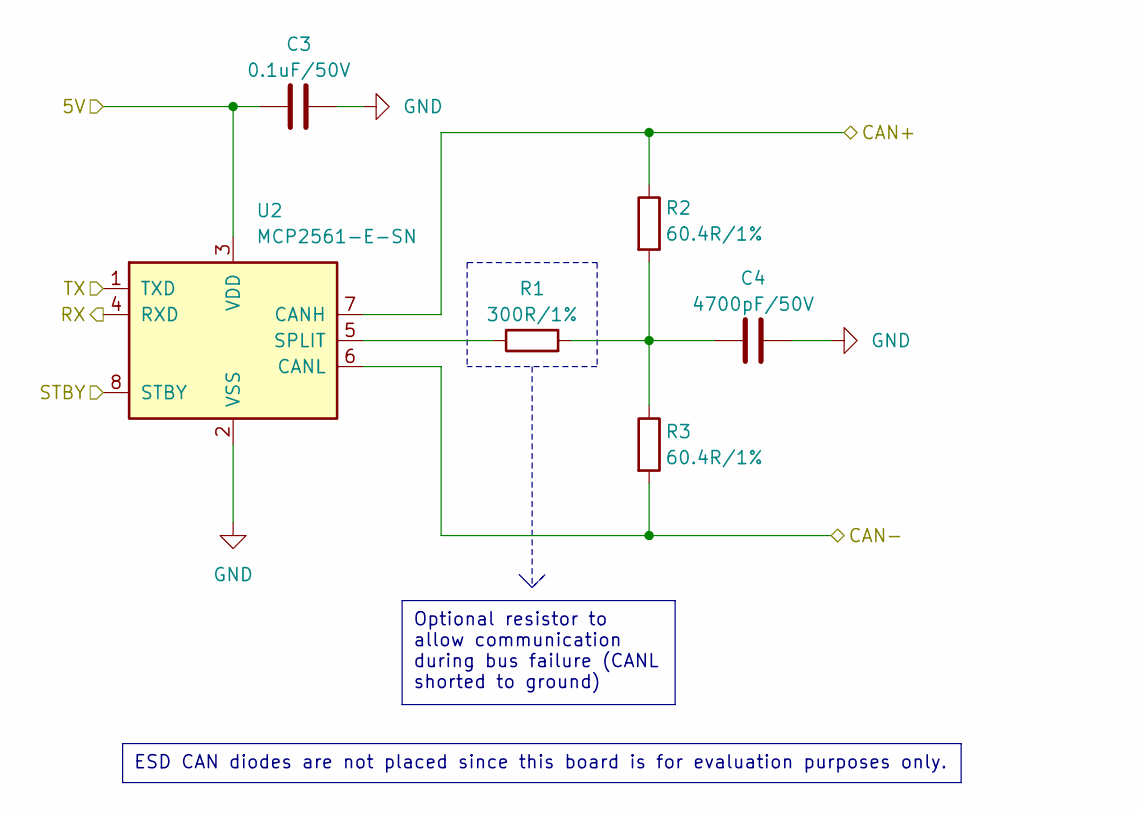
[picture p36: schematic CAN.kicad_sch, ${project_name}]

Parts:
C3: 0.1uF/50V; C_0603_1608Metric_Pad1.08x0.95mm_HandSolder; Voltage 50V; Part_Value 0.1uF
C4: 4700pF/50V; C_0603_1608Metric_Pad1.08x0.95mm_HandSolder; Voltage 50V; Part_Value 4700pF
R1: 300R/1%; R_0603_1608Metric_Pad0.98x0.95mm_HandSolder; Tolerance 1%; Part_Value 300R
R2, R3: 60.4R/1%; R_0603_1608Metric_Pad0.98x0.95mm_HandSolder; Tolerance 1%; Part_Value 60.4R
U2: MCP2561-E-SN; SOIC-8_3.9x4.9mm_P1.27mm

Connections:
/CAN/5V: C3.1, U2.3 (VDD); also elsewhere on the board
/CAN/CAN+: R2.1, U2.7 (CANH); also elsewhere on the board
/CAN/CAN-: R3.2, U2.6 (CANL); also elsewhere on the board
/CAN/RX: U2.4 (RXD); also elsewhere on the board
/CAN/STBY: U2.8 (STBY); also elsewhere on the board
/CAN/TX: U2.1 (TXD); also elsewhere on the board
GND: C3.2, C4.2, U2.2 (VSS); also elsewhere on the board
unnamed: C4.1, R1.2, R2.2, R3.1
unnamed: R1.1, U2.5 (SPLIT)

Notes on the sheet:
Optional resistor to allow communication during bus failure (CANL shorted to ground)
ESD CAN diodes are not placed since this board is for evaluation purposes only.

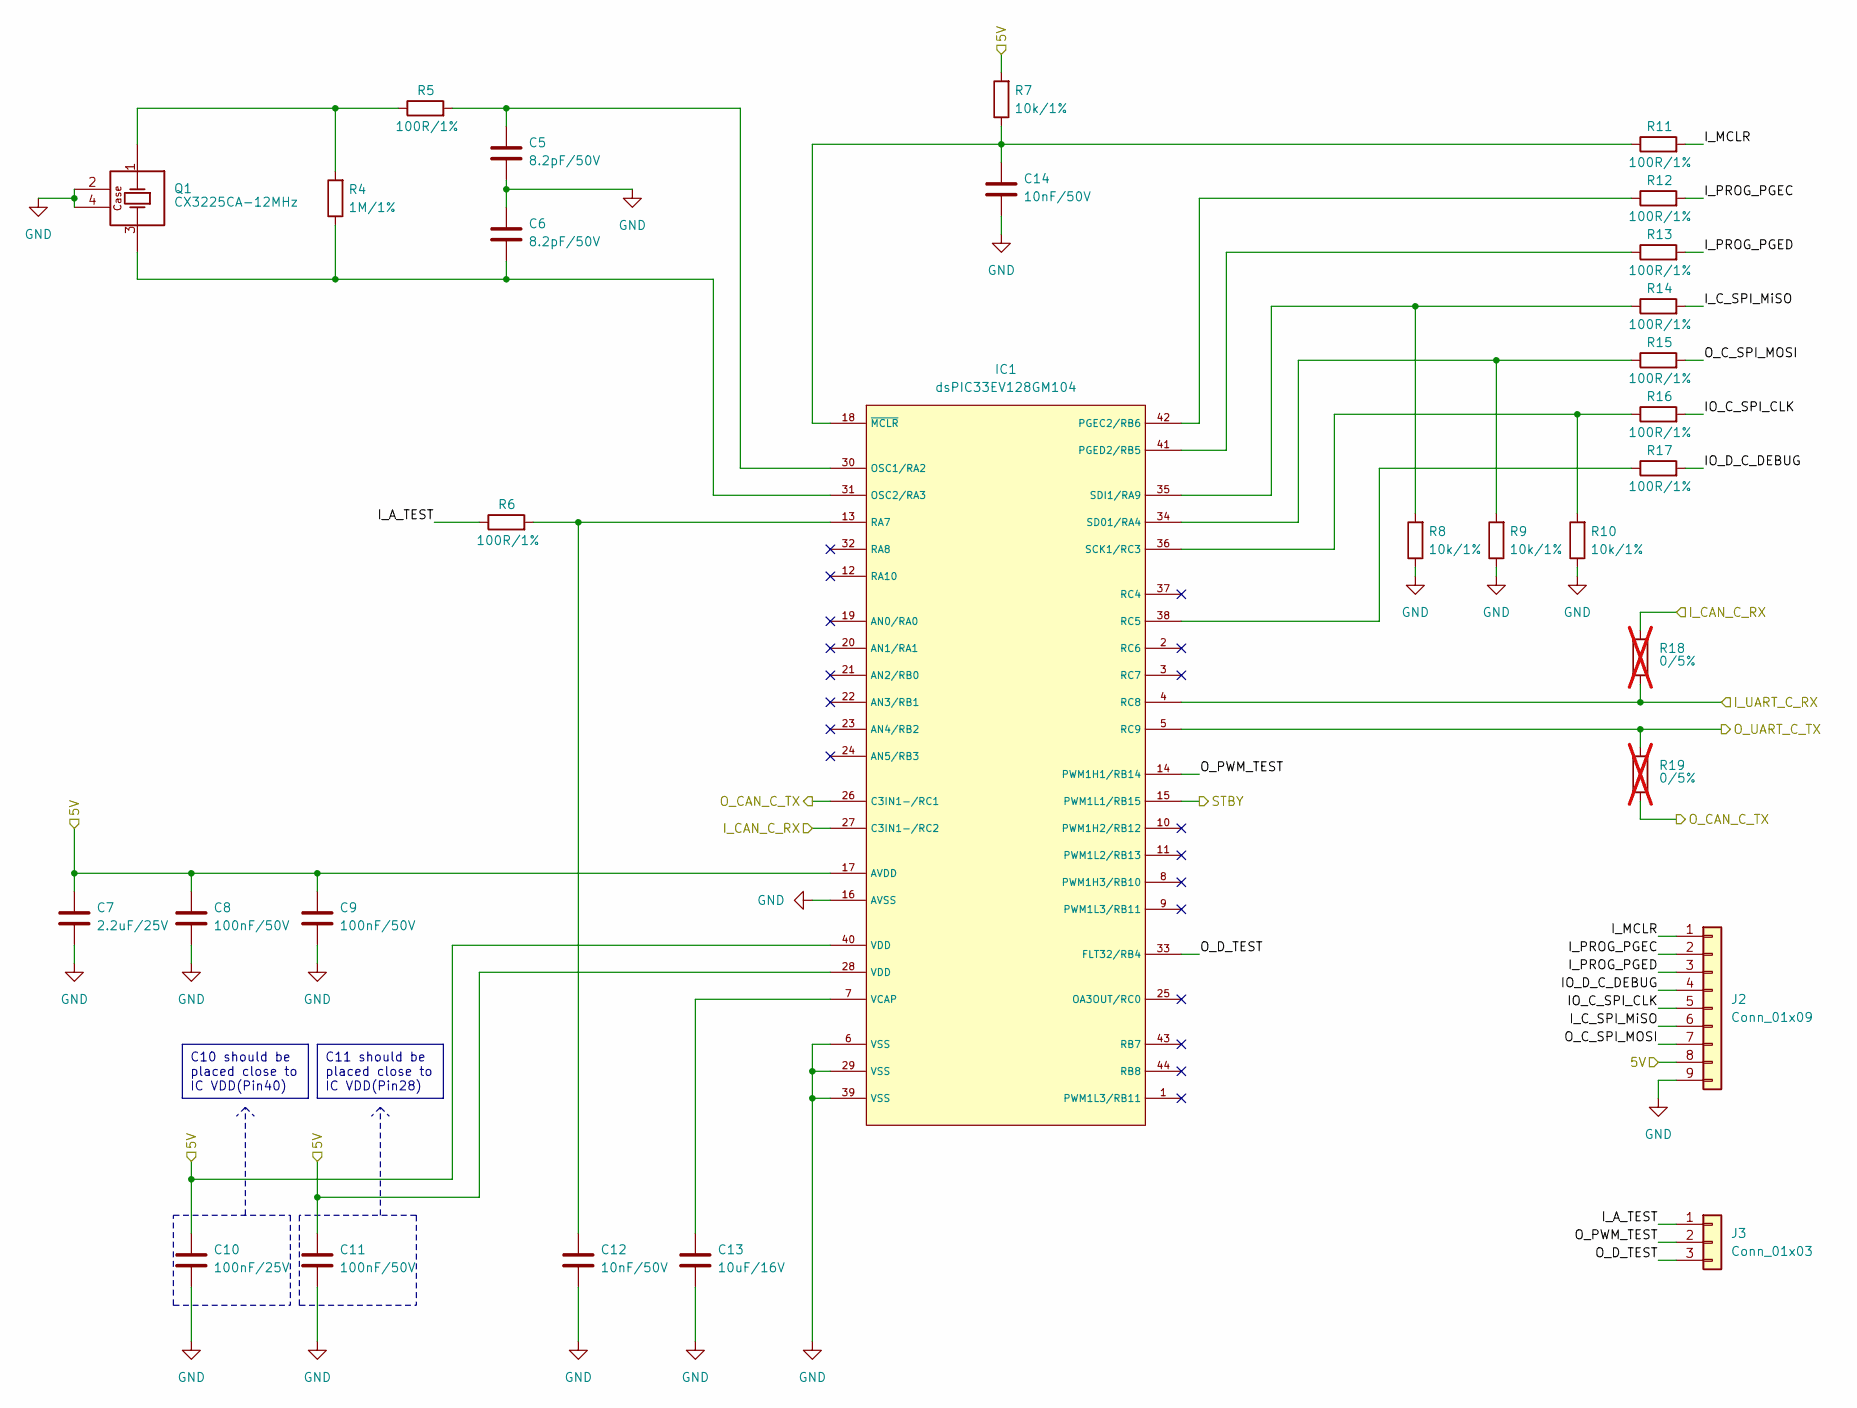
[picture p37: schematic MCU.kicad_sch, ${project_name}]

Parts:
C5, C6: 8.2pF/50V; C_0603_1608Metric_Pad1.08x0.95mm_HandSolder; Voltage 50V; Part_Value 8.2pF
C7: 2.2uF/25V; C_0603_1608Metric_Pad1.08x0.95mm_HandSolder; Voltage 25V; Part_Value 2.2uF
C8, C9, C11: 100nF/50V; C_0603_1608Metric_Pad1.08x0.95mm_HandSolder; Voltage 50V; Part_Value 100nF
C10: 100nF/25V; C_0603_1608Metric_Pad1.08x0.95mm_HandSolder; Voltage 25V; Part_Value 100nF
C12, C14: 10nF/50V; C_0603_1608Metric_Pad1.08x0.95mm_HandSolder; Voltage 50V; Part_Value 10nF
C13: 10uF/16V; C_0603_1608Metric_Pad1.08x0.95mm_HandSolder; Voltage 16V; Part_Value 10uF
IC1: dsPIC33EV128GM104; TQFP-44_10x10mm_P0.8mm
J2: Conn_01x09; PinHeader_1x09_P2.54mm_Vertical
J3: Conn_01x03; PinHeader_1x03_P2.54mm_Vertical
Q1: CX3225CA-12MHz; CX3225SB40000D0FLJCC
R4: 1M/1%; R_0603_1608Metric_Pad0.98x0.95mm_HandSolder; Tolerance 1%; Part_Value 1M
R5, R6, R11, R12, R13, R14, R15, R16, R17: 100R/1%; R_0603_1608Metric_Pad0.98x0.95mm_HandSolder; Tolerance 1%; Part_Value 100R
R7, R8, R9, R10: 10k/1%; R_0603_1608Metric_Pad0.98x0.95mm_HandSolder; Tolerance 1%; Part_Value 10k
R18, R19: 0/5%; R_0603_1608Metric_Pad0.98x0.95mm_HandSolder; Tolerance 5%; Part_Value 0; not fitted

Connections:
/CAN/5V: C7.1, C8.1, C9.1, C10.1, C11.1, IC1.17 (AVDD), IC1.28 (VDD), IC1.40 (VDD), J2.8, R7.2; also elsewhere on the board
/CAN/RX: IC1.27 (C3IN1-/RC2), R18.1; also elsewhere on the board
/CAN/STBY: IC1.15 (PWM1L1/RB15); also elsewhere on the board
/CAN/TX: IC1.26 (C3IN1-/RC1), R19.2; also elsewhere on the board
/Connector/COMM1: IC1.5 (RC9), R19.1; also elsewhere on the board
/Connector/COMM2: IC1.4 (RC8), R18.2; also elsewhere on the board
/MCU/IO_C_SPI_CLK: J2.5, R16.2
/MCU/IO_D_C_DEBUG: J2.4, R17.2
/MCU/I_A_TEST: J3.1, R6.1
/MCU/I_C_SPI_MiSO: J2.6, R14.2
/MCU/I_MCLR: J2.1, R11.2
/MCU/I_PROG_PGEC: J2.2, R12.2
/MCU/I_PROG_PGED: J2.3, R13.2
/MCU/O_C_SPI_MOSI: J2.7, R15.2
/MCU/O_D_TEST: IC1.33 (FLT32/RB4), J3.3
/MCU/O_PWM_TEST: IC1.14 (PWM1H1/RB14), J3.2
GND: C5.2, C6.1, C7.2, C8.2, C9.2, C10.2, C11.2, C12.2, C13.2, C14.2, IC1.6 (VSS), IC1.16 (AVSS), IC1.29 (VSS), IC1.39 (VSS), J2.9, Q1.2 (GND), Q1.4 (GND), R8.1, R9.1, R10.1; also elsewhere on the board
unnamed: C5.1, IC1.30 (OSC1/RA2), R5.2
unnamed: C6.2, IC1.31 (OSC2/RA3), Q1.3 (OSC2), R4.1
unnamed: IC1.42 (PGEC2/RB6), R12.1
unnamed: IC1.41 (PGED2/RB5), R13.1
unnamed: C12.1, IC1.13 (RA7), R6.2
unnamed: IC1.38 (RC5), R17.1
unnamed: IC1.36 (SCK1/RC3), R10.2, R16.1
unnamed: IC1.34 (SD01/RA4), R9.2, R15.1
unnamed: IC1.35 (SDI1/RA9), R8.2, R14.1
unnamed: C13.1, IC1.7 (VCAP)
unnamed: C14.1, IC1.18 (~MCLR), R7.1, R11.1
unnamed: Q1.1 (OSC1), R4.2, R5.1

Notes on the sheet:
C11 should be placed close to IC VDD(Pin28)
C10 should be placed close to IC VDD(Pin40)

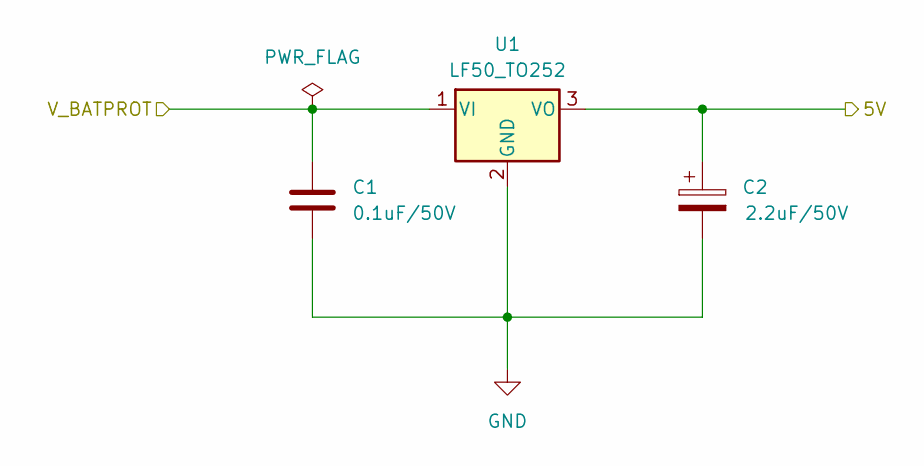
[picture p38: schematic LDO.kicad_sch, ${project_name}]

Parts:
C1: 0.1uF/50V; C_0603_1608Metric_Pad1.08x0.95mm_HandSolder; Voltage 50V; Part_Value 0.1uF
C2: 2.2uF/50V; CP_Elec_4x5.3; Voltage 50V; Part_Value 2.2uF
U1: LF50_TO252; LF50CDTTRY

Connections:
/CAN/5V: C2.1, U1.3 (VO); also elsewhere on the board
/LDO/V_BATPROT: C1.1, U1.1 (VI); also elsewhere on the board
GND: C1.2, C2.2, U1.2 (GND); also elsewhere on the board

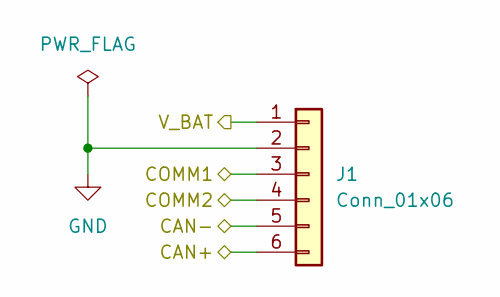
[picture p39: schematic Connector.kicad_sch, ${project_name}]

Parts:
J1: Conn_01x06; PinHeader_1x06_P2.54mm_Vertical

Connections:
/CAN/CAN+: J1.6; also elsewhere on the board
/CAN/CAN-: J1.5; also elsewhere on the board
/Connector/COMM1: J1.3; also elsewhere on the board
/Connector/COMM2: J1.4; also elsewhere on the board
/Connector/V_BAT: J1.1; also elsewhere on the board
GND: J1.2; also elsewhere on the board

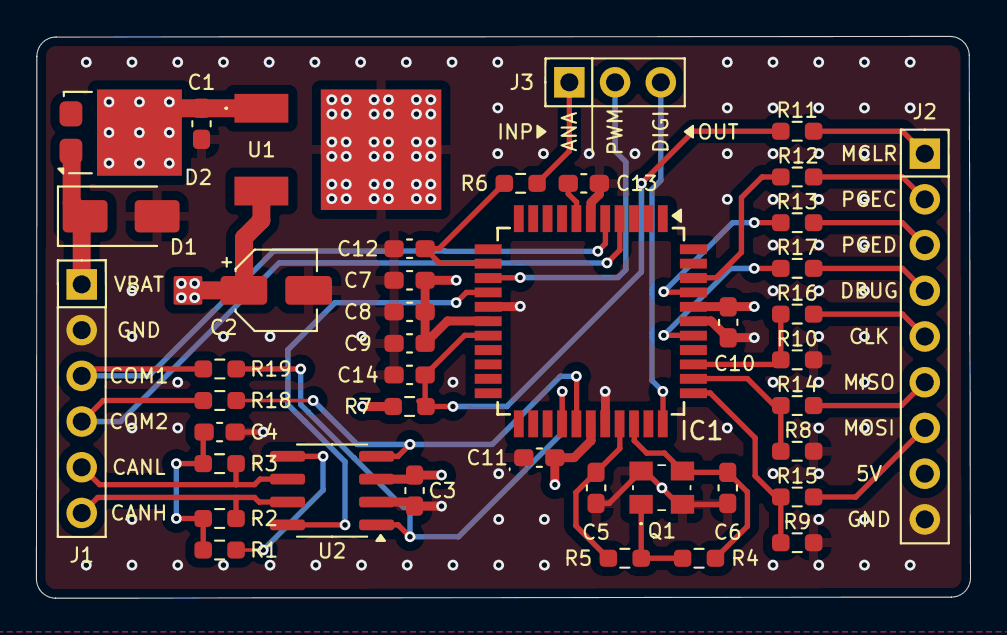
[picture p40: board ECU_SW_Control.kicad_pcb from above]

Board: 4 copper layers, 51.9 x 31.2 mm, 42 parts (0 on the bottom side), 35 nets.

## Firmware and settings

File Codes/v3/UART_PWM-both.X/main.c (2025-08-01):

#include "mcc_generated_files/system.h"        // MCC-generated system initialization
#include "mcc_generated_files/uart1.h"          // UART1 communication functions
#include <stdlib.h>                             // For atoi()

#define FCY 3685000UL  // i?lemcinin gerçek Fcy de?eri


// Global variables to store current PWM settings
volatile unsigned int global_duty_percent = 50;    // Default duty cycle: 50%
volatile unsigned int global_freq_hz = 310;        // Default frequency: 310 Hz

// Initializes PWM1H output on RB14
void PWM1_Init(void) {
    PTCONbits.PTEN = 0;                           // Disable PWM module
    PTCON2bits.PCLKDIV = 0;                       // PWM time base clock prescaler: 1:1

    // Calculate initial period based on frequency
    PTPER = (FCY / global_freq_hz) - 1;
    PDC1 = ((PTPER + 1UL) * global_duty_percent) / 100;   // Set initial duty cycle

    // Basic PWM configuration
    PWMCON1bits.ITB = 0;      // Not using independent time base
    PWMCON1bits.MDCS = 0;     // Not using master duty cycle
    PWMCON1bits.DTC = 0;      // No dead-time

    // Configure RB14 (PWM1H) as PWM output
    IOCON1bits.PENH = 1;
    IOCON1bits.PENL = 0;
    IOCON1bits.PMOD = 0;      // Edge-aligned mode

    PTCONbits.PTEN = 1;       // Enable PWM module
}

// Sets the PWM duty cycle (0 to 100%)
void PWM1_SetDutyPercent(unsigned int percent) {
    if (percent <= 100) {
        global_duty_percent = percent;
        PDC1 = ((PTPER + 1UL) * global_duty_percent) / 100;
    }
}

// Sets the PWM frequency in Hz
void PWM1_SetFrequency(unsigned int freq_hz) {
    if (freq_hz >= 310 && freq_hz <= 9000) { // Frequency range control
        global_freq_hz = freq_hz;
        PTPER = (FCY / global_freq_hz) - 1;
        PDC1 = ((PTPER + 1UL) * global_duty_percent) / 100;
    }
}

int main(void) {
    SYSTEM_Initialize();
    PWM1_Init();

    char uart_buffer[10];
    uint8_t index = 0;

    while (1) {
        // Bootloader trigger: 'b' karakteri gelirse reset at
        if (UART1_IsRxReady()) {
            char c = UART1_Read();

            if (c == 'b') {
                __asm__ volatile ("reset"); // Reset to bootloader
            }

            // Normal UART command buffer
            if (c >= '0' && c <= '9') {
                uart_buffer[index++] = c;
                if (index >= sizeof(uart_buffer)) index = 0;
            } else if (c == 'D') {
                uart_buffer[index] = '\0';
                PWM1_SetDutyPercent(atoi(uart_buffer));
                index = 0;
            } else if (c == 'F') {
                uart_buffer[index] = '\0';
                PWM1_SetFrequency(atoi(uart_buffer));
                index = 0;
            } else {
                index = 0; // Hatal? karakterde buffer'? s?f?rla
            }
        }
    }

    return 1;
}

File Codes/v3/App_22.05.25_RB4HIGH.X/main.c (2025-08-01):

#include "mcc_generated_files/system.h"
#include "mcc_generated_files/uart1.h"

int main(void)
{
    SYSTEM_Initialize();

    while (1)
    {
        // UART'tan 'b' karakteri al?n?rsa bootloader'a dönmek için reset at
        if (UART1_IsRxReady())
        {
            char c = UART1_Read();
            if (c == 'b')
            {
                __asm__ volatile ("reset");  // yaz?l?msal reset
            }
        }

        // RB4 pinini HIGH yap (örnek uygulama)
        LATBbits.LATB4 = 1;
    }

    return 1;
}
